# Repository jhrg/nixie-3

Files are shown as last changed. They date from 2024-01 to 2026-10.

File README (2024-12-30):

An alternative to the ShiftRegister74HC595 library is the builtin
shiftOut() function that is part of the Arduino IDE/libraries.

``` 
byte leds = 0;
bitSet(leds, i);

/*
 * updateShiftRegister() - This function sets the latchPin to low,
 * then calls the Arduino function 'shiftOut' to shift out contents
 * of variable 'leds' in the shift register before putting the 'latchPin' high again.
 */
void updateShiftRegister() {
    digitalWrite(latchPin, LOW);
    shiftOut(dataPin, clockPin, LSBFIRST, leds);
    digitalWrite(latchPin, HIGH);
}
```

Faster pin reads. See https://forum.arduino.cc/t/digital-read-write-pinmode-fast-execution/89116

// --- PIN MODE: OUTPUT  --- 

  DDRD |= _BV (0); // pinMode (0, OUTPUT);
  DDRD |= _BV (1); // pinMode (1, OUTPUT);
  DDRD |= _BV (2); // pinMode (2, OUTPUT);
  DDRD |= _BV (3); // pinMode (3, OUTPUT);
  DDRD |= _BV (4); // pinMode (4, OUTPUT);
  DDRD |= _BV (5); // pinMode (5, OUTPUT);
  DDRD |= _BV (6); // pinMode (6, OUTPUT);
  DDRD |= _BV (7); // pinMode (7, OUTPUT);
  DDRB |= _BV (0); // pinMode (8, OUTPUT);
  DDRB |= _BV (1); // pinMode (9, OUTPUT);
  DDRB |= _BV (2); // pinMode (10, OUTPUT);
  DDRB |= _BV (3); // pinMode (11, OUTPUT);
  DDRB |= _BV (4); // pinMode (12, OUTPUT);
  DDRB |= _BV (5); // pinMode (13, OUTPUT);
  DDRC |= _BV (0); // pinMode (A0, OUTPUT);
  DDRC |= _BV (1); // pinMode (A1, OUTPUT);
  DDRC |= _BV (2); // pinMode (A2, OUTPUT);
  DDRC |= _BV (3); // pinMode (A3, OUTPUT);
  DDRC |= _BV (4); // pinMode (A4, OUTPUT);
  DDRC |= _BV (5); // pinMode (A5, OUTPUT);

// --- PIN MODE: INPUT  --- 

  DDRD &= ~_BV (0); // pinMode (0, INPUT);
  DDRD &= ~_BV (1); // pinMode (1, INPUT);
  DDRD &= ~_BV (2); // pinMode (2, INPUT);
  DDRD &= ~_BV (3); // pinMode (3, INPUT);
  DDRD &= ~_BV (4); // pinMode (4, INPUT);
  DDRD &= ~_BV (5); // pinMode (5, INPUT);
  DDRD &= ~_BV (6); // pinMode (6, INPUT);
  DDRD &= ~_BV (7); // pinMode (7, INPUT);
  DDRB &= ~_BV (0); // pinMode (8, INPUT);
  DDRB &= ~_BV (1); // pinMode (9, INPUT);
  DDRB &= ~_BV (2); // pinMode (10, INPUT);
  DDRB &= ~_BV (3); // pinMode (11, INPUT);
  DDRB &= ~_BV (4); // pinMode (12, INPUT);
  DDRB &= ~_BV (5); // pinMode (13, INPUT);
  DDRC &= ~_BV (0); // pinMode (A0, INPUT);
  DDRC &= ~_BV (1); // pinMode (A1, INPUT);
  DDRC &= ~_BV (2); // pinMode (A2, INPUT);
  DDRC &= ~_BV (3); // pinMode (A3, INPUT);
  DDRC &= ~_BV (4); // pinMode (A4, INPUT);
  DDRC &= ~_BV (5); // pinMode (A5, INPUT);

// --- DIGITAL WRITE: HIGH  --- 

  PORTD |= _BV (0); // digitalWrite (0, HIGH);
  PORTD |= _BV (1); // digitalWrite (1, HIGH);
  PORTD |= _BV (2); // digitalWrite (2, HIGH);
  PORTD |= _BV (3); // digitalWrite (3, HIGH);
  PORTD |= _BV (4); // digitalWrite (4, HIGH);
  PORTD |= _BV (5); // digitalWrite (5, HIGH);
  PORTD |= _BV (6); // digitalWrite (6, HIGH);
  PORTD |= _BV (7); // digitalWrite (7, HIGH);

  PORTB |= _BV (0); // digitalWrite (8, HIGH);
  PORTB |= _BV (1); // digitalWrite (9, HIGH);
  PORTB |= _BV (2); // digitalWrite (10, HIGH);
  PORTB |= _BV (3); // digitalWrite (11, HIGH);
  PORTB |= _BV (4); // digitalWrite (12, HIGH);
  PORTB |= _BV (5); // digitalWrite (13, HIGH);

  PORTC |= _BV (0); // digitalWrite (A0, HIGH);
  PORTC |= _BV (1); // digitalWrite (A1, HIGH);
  PORTC |= _BV (2); // digitalWrite (A2, HIGH);
  PORTC |= _BV (3); // digitalWrite (A3, HIGH);
  PORTC |= _BV (4); // digitalWrite (A4, HIGH);
  PORTC |= _BV (5); // digitalWrite (A5, HIGH);

// --- DIGITAL WRITE: LOW  --- 

  PORTD &= ~_BV (0); // digitalWrite (0, LOW);
  PORTD &= ~_BV (1); // digitalWrite (1, LOW);
  PORTD &= ~_BV (2); // digitalWrite (2, LOW);
  PORTD &= ~_BV (3); // digitalWrite (3, LOW);
  PORTD &= ~_BV (4); // digitalWrite (4, LOW);
  PORTD &= ~_BV (5); // digitalWrite (5, LOW);
  PORTD &= ~_BV (6); // digitalWrite (6, LOW);
  PORTD &= ~_BV (7); // digitalWrite (7, LOW);

  PORTB &= ~_BV (0); // digitalWrite (8, LOW);
  PORTB &= ~_BV (1); // digitalWrite (9, LOW);
  PORTB &= ~_BV (2); // digitalWrite (10, LOW);
  PORTB &= ~_BV (3); // digitalWrite (11, LOW);
  PORTB &= ~_BV (4); // digitalWrite (12, LOW);
  PORTB &= ~_BV (5); // digitalWrite (13, LOW);
  
  PORTC &= ~_BV (0); // digitalWrite (A0, LOW);
  PORTC &= ~_BV (1); // digitalWrite (A1, LOW);
  PORTC &= ~_BV (2); // digitalWrite (A2, LOW);
  PORTC &= ~_BV (3); // digitalWrite (A3, LOW);
  PORTC &= ~_BV (4); // digitalWrite (A4, LOW);
  PORTC &= ~_BV (5); // digitalWrite (A5, LOW);

// --- DIGITAL READ  --- 

  x = (PIND & _BV (0)) == 0; // digitalRead (0);
  x = (PIND & _BV (1)) == 0; // digitalRead (1);
  x = (PIND & _BV (2)) == 0; // digitalRead (2);
  x = (PIND & _BV (3)) == 0; // digitalRead (3);
  x = (PIND & _BV (4)) == 0; // digitalRead (4);
  x = (PIND & _BV (5)) == 0; // digitalRead (5);
  x = (PIND & _BV (6)) == 0; // digitalRead (6);
  x = (PIND & _BV (7)) == 0; // digitalRead (7);
  x = (PINB & _BV (0)) == 0; // digitalRead (8);
  x = (PINB & _BV (1)) == 0; // digitalRead (9);
  x = (PINB & _BV (2)) == 0; // digitalRead (10);
  x = (PINB & _BV (3)) == 0; // digitalRead (11);
  x = (PINB & _BV (4)) == 0; // digitalRead (12);
  x = (PINB & _BV (5)) == 0; // digitalRead (13);
  x = (PINC & _BV (0)) == 0; // digitalRead (A0);
  x = (PINC & _BV (1)) == 0; // digitalRead (A1);
  x = (PINC & _BV (2)) == 0; // digitalRead (A2);
  x = (PINC & _BV (3)) == 0; // digitalRead (A3);
  x = (PINC & _BV (4)) == 0; // digitalRead (A4);
  x = (PINC & _BV (5)) == 0; // digitalRead (A5);

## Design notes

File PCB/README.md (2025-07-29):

## Ideal Project Structure

    my_kicad_project/
    ├── my_project.kicad_sch
    ├── my_project.kicad_pcb
    ├── my_project.kicad_pro
    ├── footprints/
    │   └── custom_footprint.pretty/
    └── symbols/
        └── custom_symbol.kicad_sym

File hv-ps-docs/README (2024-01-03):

Scope images showing the affect of adding a resistor from the anode to
ground (marked 'w-gnd') so that anode current can drain off when using
PWM to control brightness of a nixe tube. Measured using the 'nixe-3'
board where each tube has its own BCD to dec driver 74151 which
are each connected to a 74HC595 serial to 8-bit parallel chip.

This shows that adding the resistor does not make much difference in the
turn off time and no difference in the turn on time. The images were taken
at the brightest and dimest PWN settings.

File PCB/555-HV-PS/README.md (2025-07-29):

# 555 HV Power supply for Nixie tubes

This is a power supply for nixie tubes based on the 555 timer chip. The 555 is configured in its astable mode with a frequency of ~32kHz.

When I used this, it has some ripple in the output and there is some slight ghosting of the digits that I think is from noise affecting the serial output to the nixie 3.2 driver board. When I use a commercial supply that has cleaner output, there is no ghosting. However, it might be that noise from my breadboard version of the HV PS is the problem and not the output itself.

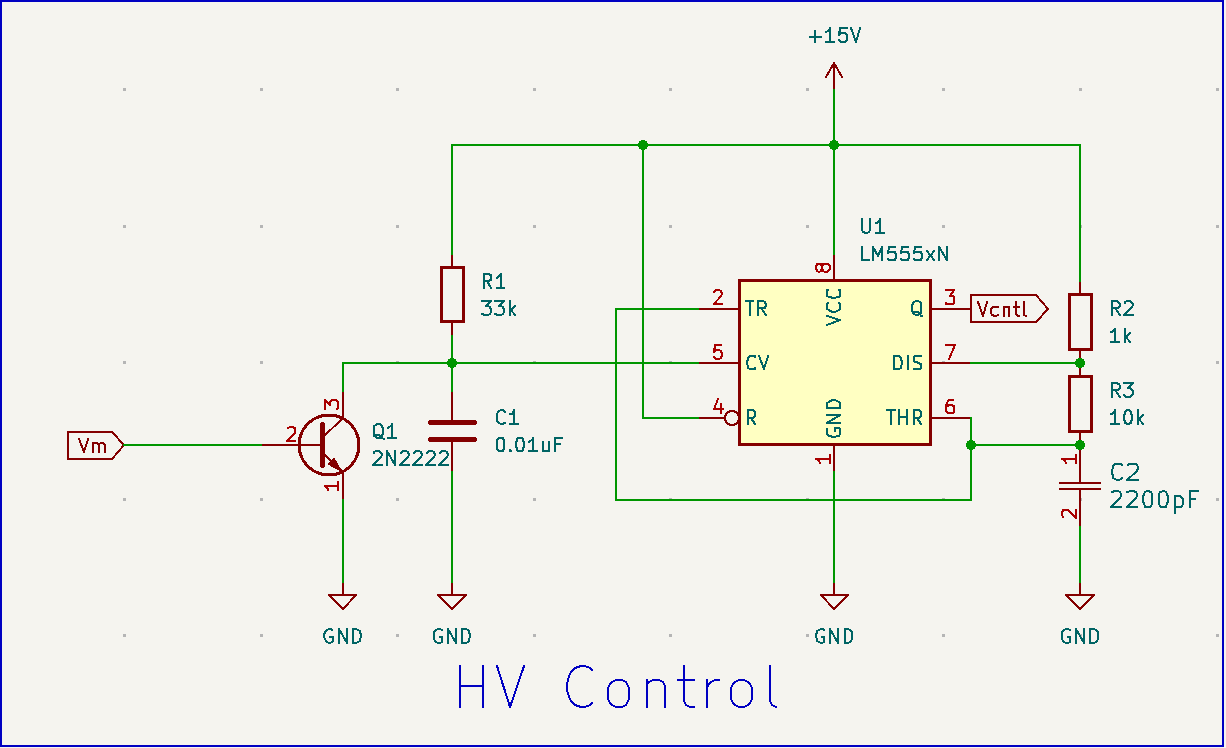
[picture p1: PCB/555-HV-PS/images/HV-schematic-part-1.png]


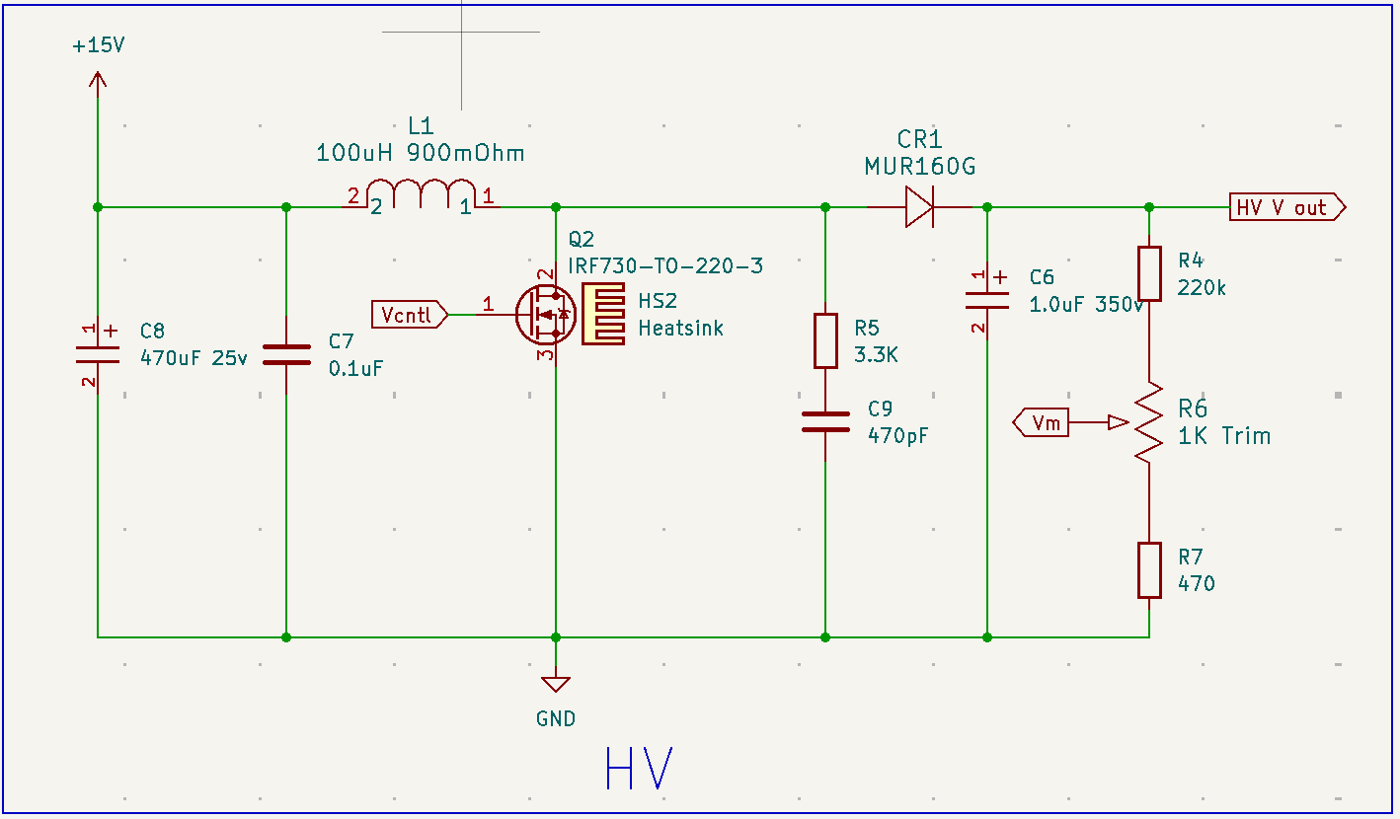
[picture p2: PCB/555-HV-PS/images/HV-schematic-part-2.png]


## About the RC snubber

R5 and C9 are a RC snubber to limit ringing at the from Q2 when it switches off. 
In these images, yellow is the hig voltage at the inductor-diode-Q2 junction or the
HV output of the PS and magenta is the switching voltage from pin 3 of the 555 (i.e.,
the gate of Q2).

Without the RC snubber, there is ringing when Q2 turns off:

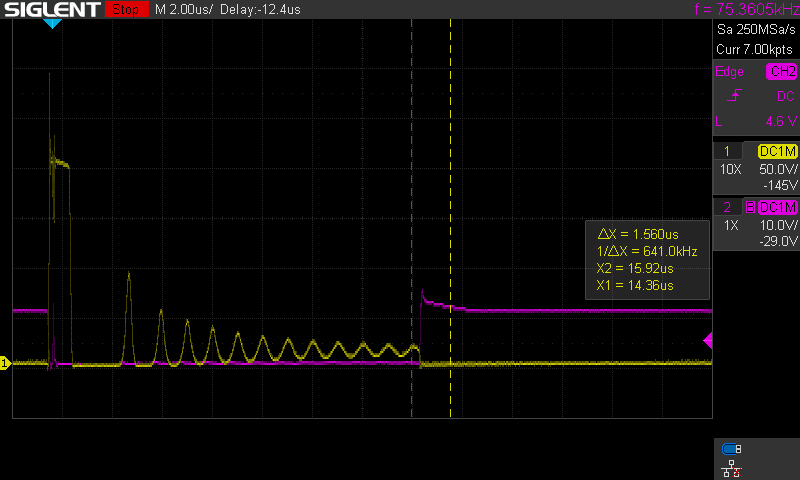
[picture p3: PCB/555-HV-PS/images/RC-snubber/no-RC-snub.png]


The snubber circuit can damp this ringing - that might help clean up the output.
Here are the effects of various values of R5 and C9. I choose R5 at 15k and C9
as 100pF initially based on info from [DigiKey's article on RC snubbers for power switches](https://www.digikey.com/en/articles/resistor-capacitor-rc-snubber-design-for-power-switches).

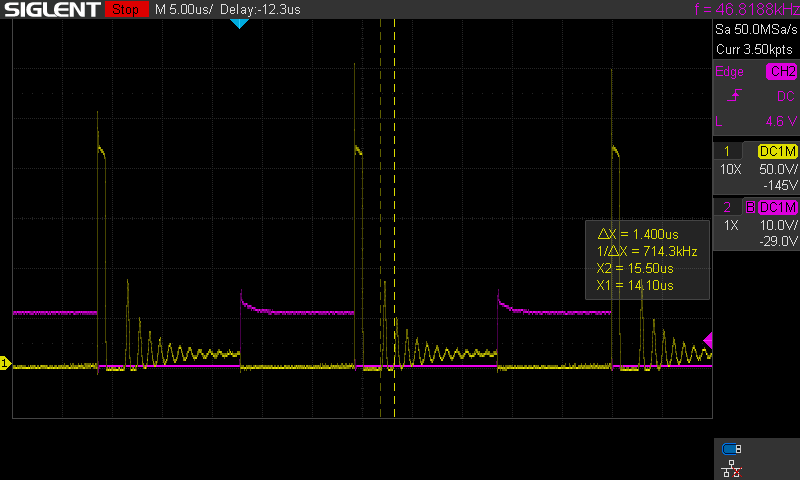
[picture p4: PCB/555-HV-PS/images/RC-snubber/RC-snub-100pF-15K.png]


Some improvement.

Dropping R5 down to 1K makes a bigger difference, but the efficiency of the PS
drops (the current draw goes from 370mA to 400mA):

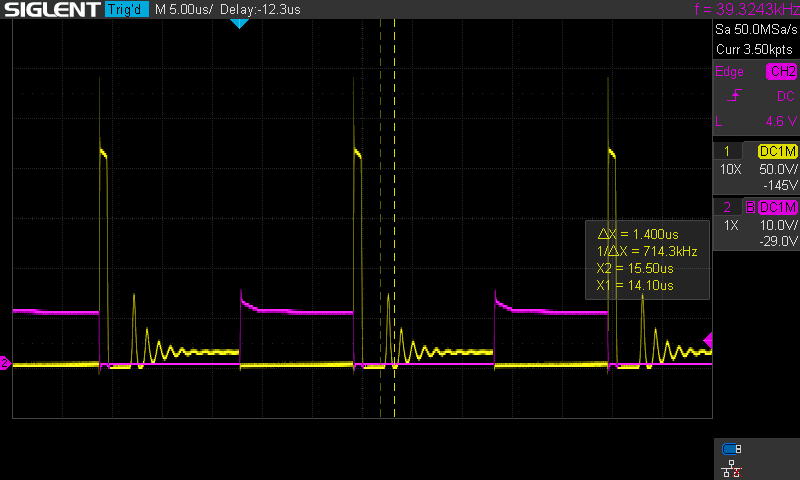
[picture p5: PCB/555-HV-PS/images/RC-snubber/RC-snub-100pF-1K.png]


Increasing C9 to 470pF makes an even bigger improvement, but the PS is still drawing 400mA
@12V from the bench supply:

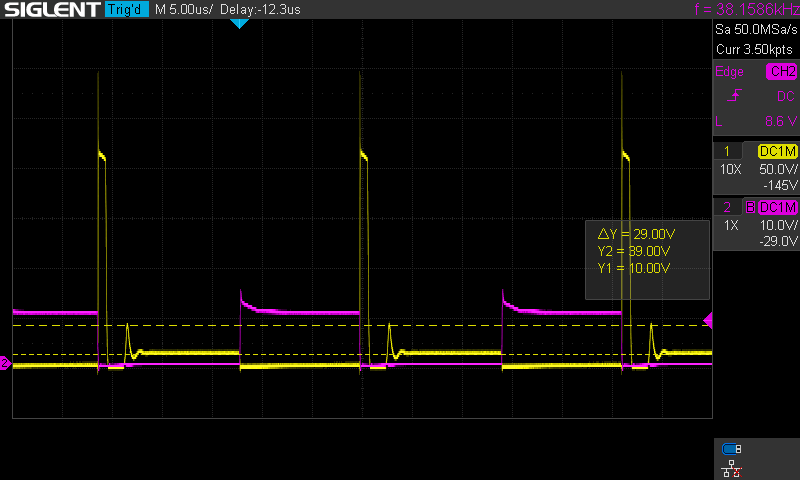
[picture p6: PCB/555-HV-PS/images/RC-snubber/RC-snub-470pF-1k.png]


Increasing R5 to 3.3K reduces the power needed (back to 370mA @12V) with decent damping:

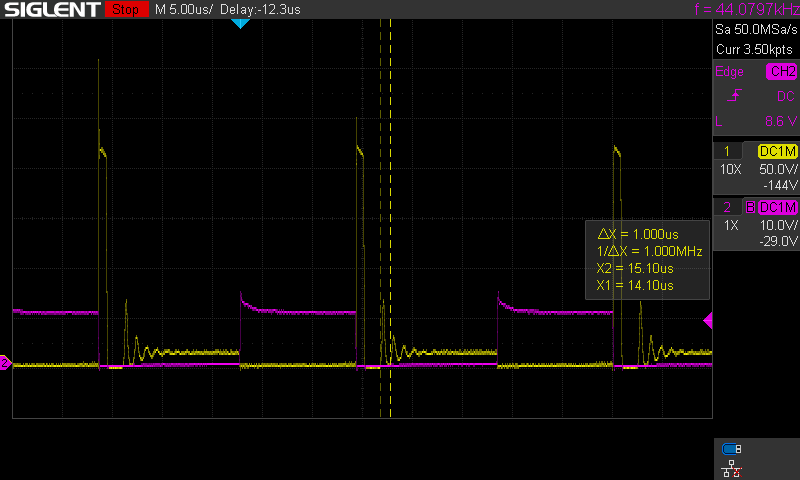
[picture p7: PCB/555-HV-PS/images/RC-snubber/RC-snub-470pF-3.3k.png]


The output of the PS looks like:

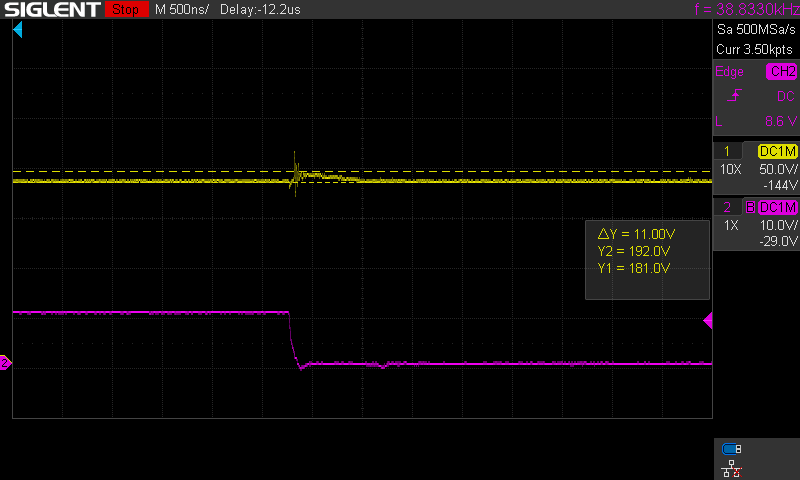
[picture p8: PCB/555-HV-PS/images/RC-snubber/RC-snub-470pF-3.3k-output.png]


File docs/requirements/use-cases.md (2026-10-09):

<!-- CONTRACT: actor-driven flows through the system. Each use case is what ties
     functional requirements together into something a real user actually does.
     Delete the _EXAMPLE_ use case once you've seen the shape. -->

# Use Cases

Convention: `UC-###`. Each use case follows the template below. Link related `FR-###`
/ `NFR-###` IDs at the bottom so `/trace` can find them in both directions.

---

## UC-001 — Adjust display brightness

**Actor(s):** Day-to-day user of the clock

**Trigger:** Quick (momentary) press of button 1

**Preconditions:** Clock is powered on and running (any display mode)

**Main flow:**
1. User gives a quick press on button 1
2. System advances to the next brightness level in the preset sequence
   (`brightness_count`), wrapping back to the brightest level after the dimmest
3. System applies the new PWM level to the HV brightness control pin immediately

**Alternate / exception flows:**
- None currently handled — every quick press of button 1 advances brightness
  regardless of current display mode

**Postconditions:** Display brightness is at the newly selected preset level until
the next quick press

**Related requirements:** FR-003

---

## UC-002 — Switch between MM:SS and HH:MM display mode

**Actor(s):** Day-to-day user of the clock

**Trigger:** Quick (momentary) press of button 2

**Preconditions:** Clock is powered on and running

**Main flow:**
1. User gives a quick press on button 2
2. System toggles the display mode between `mm_ss` and `hh_mm`
3. System renders the four Nixie tubes using the digits for the newly selected mode
   on the next time-update tick

**Alternate / exception flows:**
- None currently handled — medium (~2s) and long (~5s) presses of either button are
  currently no-ops, reserved for a future task/feature

**Postconditions:** Clock continues displaying time in the newly selected mode until
the next quick press of button 2

**Related requirements:** FR-001

---

<!-- Copy the template above for each new use case. Sequential UC-### heading,
     same subsection order, so /trace can parse it. -->

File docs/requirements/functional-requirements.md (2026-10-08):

<!-- CONTRACT: what the system must DO. One row per requirement. IDs are permanent —
     never renumbered or reused. Dropped requirements get Status: Deprecated /
     Superseded, not deleted. Delete the _EXAMPLE_ row once you've seen the shape. -->

# Functional Requirements

Convention: `FR-###`, zero-padded, assigned sequentially by next-highest-number.
Priority: `Must` / `Should` / `Could` (MoSCoW). Status: `Proposed` / `Approved` /
`Implemented` / `Deprecated` / `Superseded by FR-0XX`.

| ID | Requirement | Priority | Related Use Cases | Status |
|---|---|---|---|---|
| FR-001 | Display the current time on four Nixie tubes, switchable between MM:SS and HH:MM modes via a button press | Must | UC-002 | Implemented |
| FR-002 | Maintain accurate time using an external RTC (DS3231 or DS1307) that survives power cycles | Must | — | Implemented |
| FR-003 | Allow brightness adjustment via a push-button that cycles through preset PWM brightness levels | Must | UC-001 | Implemented |
| FR-004 | Flash the colon/separator once per second as a visible seconds indicator | Must | — | Implemented |

<!-- Add new rows via /new-requirement, or by hand — keep the table format. Each
     requirement should be a single testable statement, not a paragraph. If it needs
     a paragraph, it's probably a use case (docs/requirements/use-cases.md) with this
     as one of its acceptance criteria. -->

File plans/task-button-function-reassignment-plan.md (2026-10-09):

# Task Plan: Reassign button functions: button 1 = brightness, button 2 = display mode

**Task:** TASK-002
**Status:** Done
**Created:** 2026-10-08

## Summary

Swap which button drives which action: button 1's quick press keeps controlling
brightness, button 2's quick press takes over display-mode toggling (currently that's
a ~2s hold on button 1). Both buttons' medium (~2s) and long (~5s) presses become
explicit no-ops, reserved for future use. UC-001 and UC-002 are updated to match.

## Motivation

Today both buttons' quick presses do the identical thing (advance brightness), and
mode-switching is hidden behind a 2-second hold on button 1 that a user has to
discover or be told about. Splitting the two actions across the two buttons' quick
presses gives each button a distinct, easily-discoverable role, and frees up the
medium/long press duration on *both* buttons for a future task or feature (per user
request — out of scope here).

## Related requirements / constraints

- FR-001 — "switchable between MM:SS and HH:MM modes via a button press." Wording
  doesn't name a specific button, so no FR text change is needed; the use case that
  specializes it (UC-002) does need updating.
- FR-003 — "brightness adjustment via a push-button that cycles through preset PWM
  brightness levels." Same situation: button-agnostic wording, no FR change needed.
- UC-001 (Adjust display brightness) — currently documents the trigger as "quick
  press of button 1 or button 2." Updated by this task to "button 1" only.
- UC-002 (Switch between MM:SS and HH:MM) — currently documents the trigger as "medium
  press (~2s) of button 1." Updated by this task to "quick press of button 2."
- No IC/ADR found that bears on this change.

## Scope

**In scope:**
- `src/main.cpp`, `loop()`:
  - Button 1 (`read_button_1()`) switch: `quick` keeps calling
    `input_switch_quick_press()` (unchanged behavior). `medium_2s` and `long_5s`
    become explicit no-op cases (currently `medium_2s` calls
    `input_switch_medium_press()`; `long_5s` already falls through `default`).
  - Button 2 (`read_button_2()`) switch: `quick` calls the display-mode toggle
    (currently `input_switch_medium_press()`, invoked from button 1's `medium_2s`
    case) instead of `input_switch_quick_press()`. `medium_2s` and `long_5s` become
    explicit no-op cases (`medium_2s` is already a no-op today but implicit; make it
    explicit alongside `long_5s` for symmetry).
  - Rename `input_switch_medium_press()` to a name that doesn't reference "medium"
    duration, since it's no longer tied to a medium-length press (e.g.
    `toggle_display_mode()`). Logic inside the function is unchanged.
  - Remove the stale `// Replace this with ...` comment above button 2's switch,
    since this task is exactly that replacement.
  - Add a short comment on each new no-op case noting it's reserved for a future
    task/feature, so the empty branch doesn't read as an oversight.
- `docs/requirements/use-cases.md`:
  - UC-001: change Trigger to "Quick (momentary) press of button 1." Update the main
    flow's "either push button" wording to "button 1." Update/remove the alternate
    flow note that currently says "every quick press advances brightness regardless
    of current display mode" if it no longer applies, or reword to reflect
    single-button triggering.
  - UC-002: change Trigger to "Quick (momentary) press of button 2." Update the main
    flow's "holds button 1 for a medium press duration" wording to "gives a quick
    press on button 2." Replace the alternate-flow note about button 2's medium press
    having no assigned behavior — that's now moot — with a note that both buttons'
    medium (~2s) and long (~5s) presses are currently no-ops, reserved for future use.
- `docs/tasks/TASK-LOG.md`: already updated to `Plan Ready` with this plan linked.

**Out of scope:**
- `include/button_timing.h` / `src/button_timing.cc` — press-duration classification,
  thresholds (`SWITCH_PRESS_2S`/`SWITCH_PRESS_5S`), and debounce timing are untouched.
  TASK-001 (native test env + extraction of this module) is independent of this
  rewiring and currently `In Progress`; this task doesn't depend on it finishing.
- `read_button_1()` / `read_button_2()`, the ISR handlers, or `mode_switch_setup()` in
  `src/mode_switch2.cc` — press detection and debouncing logic is unchanged.
- Any assigned behavior for the medium (~2s) or long (~5s) presses on either button —
  explicitly deferred to a future task/feature per the user's request.
- FR-001 / FR-003 wording — already button-agnostic, no change needed.
- Adding a native unit test for the button-dispatch `switch` statements in
  `loop()` — this logic is tightly coupled to Arduino globals (`analogWrite`,
  `the_display_mode`, `brightness`) and isn't extracted into a testable module;
  extracting it would be new scope (and overlaps what TASK-001 is already doing for
  the press-duration side), not part of this reassignment.
- Any change to pin assignments, ISR attachment, or interrupt trigger types in
  `include/pins.h` or `mode_switch_setup()`.

## Approach

1. In `src/main.cpp`, rename `input_switch_medium_press()` to `toggle_display_mode()`
   (keep its signature/body as-is — it already takes and returns `enum
   display_mode`).
2. Rewrite button 1's `switch (read_button_1())`:
   - `case quick:` — unchanged, calls `input_switch_quick_press()`.
   - `case medium_2s:` — becomes `break;` with a one-line comment ("no-op; reserved
     for future task/feature").
   - `case long_5s:` — add explicit case with the same no-op + comment (previously
     implicit via `default`).
   - `default:` — unchanged (`break;`).
3. Rewrite button 2's `switch (read_button_2())`:
   - `case quick:` — now calls `the_display_mode =
     toggle_display_mode(the_display_mode);` instead of
     `input_switch_quick_press()`.
   - `case medium_2s:` — explicit no-op + comment (was already an empty case;
     keep it, just add the comment for symmetry with button 1).
   - `case long_5s:` — add explicit case, no-op + comment.
   - `default:` — unchanged.
   - Remove the `// Replace this with ...` comment above this switch.
4. Update `docs/requirements/use-cases.md` UC-001 and UC-002 per the Scope section
   above (Trigger, main flow wording, alternate-flow notes).
5. Build for the target env (`pio run`) to confirm it still compiles — no native
   test exists for this dispatch logic (see Out of scope), so this is a compile +
   manual/on-device check, not a unit-test pass.

Completeness check: since this only touches two `switch` statements in one function
plus one renamed function and two UC sections, completeness is verified by reading
the full diff of `src/main.cpp` and `docs/requirements/use-cases.md` against this
plan's enumerated changes above — no grep-count needed given the small, fixed set of
edit sites.

## Verification

- `pio run` builds clean for the target board environment (no new warnings beyond
  whatever baseline currently exists).
- `pio check` run against the touched file, per CLAUDE.md's static-analysis
  convention.
- Manual on-device check (per CLAUDE.md: anything that must touch real silicon is
  verified on-target, not unit tested): quick-press button 1 → brightness advances;
  quick-press button 2 → display mode toggles between MM:SS and HH:MM; hold either
  button ~2s or ~5s → nothing happens.
- Diff review of `src/main.cpp` and `docs/requirements/use-cases.md` against the
  Scope section to confirm nothing beyond the listed edit sites changed.

## Risks

- `toggle_display_mode()`'s rename could miss a call site if one exists outside
  `main.cpp` — mitigated by grepping for `input_switch_medium_press` before and after
  to confirm zero remaining references.
- Since button 2's quick press previously shared `input_switch_quick_press()` with
  button 1, removing that call means button 2 no longer touches `brightness`/
  `HV_PWM_CONTROL` at all — worth confirming no other code path assumed button 2
  could also drive brightness.

## Open questions

None — scope, category, and the UC-doc update were confirmed with the user before
drafting this plan.

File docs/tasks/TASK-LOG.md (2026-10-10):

<!-- CONTRACT: scoped engineering/maintenance work that isn't new capability (FR/NFR/
     UC) and isn't corrective (BUG) — dependency bumps, removing dead code or stale
     compile-time directives, retrofitting tests onto code that predates them,
     build/tooling changes. The common thread: the "right" outcome is usually
     mechanical and completeness matters (did every instance get handled?), not
     open-ended design. Delete the TASK-EXAMPLE section once you've seen the shape. -->

# Task Log

Convention: `TASK-###`, sequential, never renumbered. Status: `Open` → `Plan Ready` →
`In Progress` → `Done` (or `Won't Do` / `Superseded by TASK-0XX`). **Only the user sets
`Done`** — it's a claim about verified work, not something to self-report from having
written a plan. Category is one of: Dependency
Update, Code Cleanup, Test Coverage, Build/Tooling, Documentation (add categories as
needed).

---

## TASK-001 — Add native PlatformIO test environment, extracting button press-duration classification as a first unit-testable module

**Category:** Build/Tooling
**Status:** In Progress
**Created:** 2026-10-07
**Related requirements/constraints:** None found — stems from CLAUDE.md's testing
convention, not a tracked FR/NFR/IC. Underpins button behavior in FR-001, FR-003,
UC-001, UC-002 without changing it.
**Plan:** `plans/task-native-test-env-plan.md`

**Scope:** Add `[env:native]` to `platformio.ini`, standalone (not inheriting
`[env]`'s Arduino-only `lib_deps`/`build_flags`). Extract the press-duration
classification currently duplicated in `read_button_1()`/`read_button_2()`
(`src/mode_switch2.cc`) into `include/button_timing.h` + `src/button_timing.cc`,
with no `Arduino.h` dependency, and add a Unity test under
`test/test_button_timing/`. Does not extract any other logic (brightness
wraparound, digit-from-time computation, debounce timing itself), change button
behavior/thresholds, assign `read_button_2()`'s unused `medium_2s` case, or
introduce a `lib/` subfolder layout — each is out of scope for this task.

**Motivation:** No way currently exists to run any unit test without a board
attached; CLAUDE.md's testing convention calls for `env:native` but it was never
added. Flagged as a known gap during the `/init-planning` session rather than
invented independently.

---

## TASK-002 — Reassign button functions: button 1 = brightness, button 2 = display mode

**Category:** Code Cleanup
**Status:** In Progress
**Created:** 2026-10-08
**Related requirements/constraints:** FR-001 (mode switching via button press — wording
is button-agnostic, no change needed), FR-003 (brightness cycling via push-button —
wording is button-agnostic, no change needed). UC-001 and UC-002 explicitly document
the *current* button-to-function mapping and will be updated as part of this task to
match the new mapping.
**Plan:** `plans/task-button-function-reassignment-plan.md`

**Scope:** Rewire the button dispatch in `src/main.cpp`'s `loop()` so button 1's quick
press still drives brightness (unchanged) and button 2's quick press drives the
display-mode toggle (moved off button 1's medium ~2s press). Button 1's and button
2's medium (~2s) and long (~5s) presses become explicit no-ops. Update UC-001 and
UC-002 in `docs/requirements/use-cases.md` to describe the new mapping. Does not
touch `button_timing.cc/h`, press-duration thresholds, debounce timing, the ISR
handlers, `read_button_1()`/`read_button_2()`, or assign any behavior to the 2s/5s
presses themselves (reserved for a future task/feature) — each is out of scope.

**Motivation:** Today both buttons' quick presses do the same thing (brightness), and
mode-switching is buried behind a 2-second hold on button 1 — a less discoverable,
less evenly-distributed mapping. Reassigning gives each button a distinct quick-press
role and frees up both buttons' medium/long presses for future use, per user request.

---

## TASK-003 — Separate hardware-touching code from logic-only code for three more functions, extending TASK-001's pattern

**Category:** Code Cleanup
**Status:** Plan Ready
**Created:** 2026-10-09
**Related requirements/constraints:** None found — stems from CLAUDE.md's hardware-
adapter-layer convention, not a tracked FR/NFR/IC. The logic being extracted
underpins FR-001 (display mode), FR-003 (brightness), and FR-002/UC-002 (time
display) without changing any of their behavior.
**Plan:** `plans/task-hardware-logic-separation-plan.md`

**Scope:** Extract three more pieces of logic that TASK-001 explicitly deferred,
decoupling each from `Arduino.h` and (for the time-digit case) from RTClib's
`DateTime` type, and add a native Unity test for each: (1) the brightness-index
wraparound in `main.cpp`'s `input_switch_quick_press()`, (2) `main.cpp`'s already-pure
`toggle_display_mode()`, relocated into its own translation unit, and (3) the
digit-from-time/date decomposition in `RTC.cc`'s `update_display_with_time()` /
`update_display_with_date()`, rewritten to take plain integers instead of `DateTime`.
Does not touch debounce timing, the ISR handlers, `read_button_1()`/`read_button_2()`,
or remove `update_display_with_date()` despite it currently being unused — each is
out of scope.

**Motivation:** Sets the stage for more complete unit-test coverage by continuing the
hardware/logic separation TASK-001 started and explicitly deferred for these three
pieces, per user request.

---

<!-- Add new tasks via /plan-task, or by hand — keep the section format: metadata
     lines, then Scope / Motivation. Unlike a bug, a task doesn't need a symptom or
     reproduction — it needs a clear boundary of what's included and what isn't,
     since "remove all the X" quietly becoming "remove most of the X" is the
     characteristic failure mode here. -->

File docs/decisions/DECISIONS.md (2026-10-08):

<!-- CONTRACT: WHY things are the way they are. Never a log of what happened (that's
     git history / plans/) — only calls that could plausibly have gone another way,
     with the reasoning captured so it isn't re-litigated from scratch in six months. -->

# Decisions

Convention: `ADR-###`, sequential, never renumbered. A superseded decision stays in
the file with `Status: Superseded by ADR-0XX` — the reasoning that led somewhere wrong
is often as useful later as the reasoning that led somewhere right.

---

## ADR-EXAMPLE — Use a time-limited link, not a one-time code, for password reset

*(delete this section once you've seen the shape)*

**Date:** YYYY-MM-DD
**Status:** Accepted

**Context:** Password reset needed a mechanism that works from any device, including
one the user isn't currently signed in on.

**Decision:** Emailed link with a signed, expiring token, rather than a numeric code
entered back into the original device.

**Alternatives considered:**
- Numeric code — simpler to implement, but assumes the user is on the same device
  they requested from, which broke for a chunk of support tickets historically.

**Consequences:** Reset flow now depends on transactional email deliverability, which
becomes a new failure mode to monitor (see IC-EXAMPLE if a related constraint exists).

**Related:** FR-EXAMPLE, UC-EXAMPLE

---

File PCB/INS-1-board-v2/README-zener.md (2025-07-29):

## Zener diode power sources for INS-1 Nixie Tubes
### July 1, 2025
Asking ChatGPT about a Power supply for INS-1 Nixie tubes using a zener diode.
Here’s how you size the series resistor (and check its power) step-by-step:

1. List your parameters

Supply voltage: 
$VV_\text{in}=180\text{ V}$

Zener voltage: 
$VV_Z=91\text{V}$ (measured at its test current $I_{Zt}=4\text{ mA}$)

Tube load current: two tubes × 0.5 mA each ⇒ $I_L=1\text{ mA}$

Desired Zener bias: use the data sheet test current, 
$I_{Z,\text{bias}}=I_{Zt}=4\text{ mA}$

2. Compute resistor value
You need to supply both load and Zener bias current through RR.
$RR = \frac{V_\text{in}-V_Z}{I_L + I_{Z,\text{bias}}} =\frac{180-91}{1\,\text{ mA}+4\,\text{ mA}} =\frac{89\text{ V}}{5\text{ mA}} =17.8\text{ kΩ}$
Use the nearest standard: 18 kΩ.

3. Check currents (at any Vin variation)
At nominal 180 V:
$I_R = \frac{180-91}{18\,\text{kΩ}}\approx4.94\text{ mA} \quad\Longrightarrow\quad I_Z = I_R - I_L \approx 4.94 - 1 = 3.94\text{ mA}$
That’s essentially the 4 mA bias—right at the knee.

If the supply dipped to, say, 175 V:
 $I_R = \frac{175-91}{18\,\text{kΩ}}\approx4.67\text{ mA} \quad\Longrightarrow\quad I_Z\approx3.67\text{ mA}$
 Still above the knee current, so regulation holds.

If it rose to 185 V:
 $I_R = \frac{185-91}{18\,\text{kΩ}}\approx5.22\text{ mA} \quad\Longrightarrow\quad I_Z\approx4.22\text{ mA}$
 Well below any damaging level.

4. Check power dissipation
   1. Resistor:
 $PR=(Vin−VZ)×IR≈89 V×0.005 A=0.445 W P_R = (V_\text{in}-V_Z)\times I_R \approx 89\text{ V}\times0.005\text{ A} =0.445\text{ W}$
 ⇒ use at least a 1 W resistor (or a ½ W with good ventilation, but 1 W is safer).
   1. Zener:
 $PZ=VZ×IZ,bias=91 V×0.004 A=0.364 W P_Z = V_Z \times I_{Z,\text{bias}} =91\text{ V}\times0.004\text{ A} =0.364\text{ W}$
 ⇒ choose a Zener rated ≥ ½ W (or 1 W for head-room).

5. Final parts choice
Series resistor: 18 kΩ, 1 W

Zener diode: 91 V, ≥ 0.5 W (1 W preferred)

Optional: a small (0.1 µF–1 µF) bypass cap across the Zener if you ever see switching noise—though if your supply is very clean, it’s not strictly needed.

With that in place, your two Nixies (1 mA total) will see a rock-steady 91 V clamp, fed from your 180 V rail via the 18 kΩ/1 W resistor.

About using the common emitter-follower + zener configuration

Adding an emitter–follower (i.e. a high-voltage NPN or N-channel device acting as a buffer) behind your Zener lets the Zener only source the transistor’s base (or gate) current instead of the entire tube load.  In practice that means:

1. **Much lower Zener bias current**

   * In our straight Zener clamp, the series resistor had to supply $I_L + I_{Z}$, e.g. 1 mA for the tubes plus 4 mA for the Zener → 5 mA total.
   * With an emitter-follower, the Zener only needs to supply the transistor’s base current:

     $I_B \approx \frac{I_E}{\beta}$

     If your transistor has a DC current gain ($\beta$) of, say, 100, then for 1 mA emitter current you only need \~10 µA of base current.  You’d typically pick a few tens of µA of Zener bias (say 50 µA) to keep it in regulation—two orders of magnitude less than before.

2. **Series-resistor power drops drastically**

   * Old design:

     $P_R = (180 - 91)\,\text{V} \times 5\,\text{mA} \approx 0.445\,\text{W}$

     ⇒ needed a ≥1 W resistor.
   * Emitter-follower design: if you set $I_{Z}+I_B\approx50\,\mu\text{A}$,

     $P_R = 89\,\text{V} \times 50\,\mu\text{A} \approx 4.5\,\text{mW}$

     ⇒ a tiny 1/10 W (or even 1/20 W) part is plenty.

3. **Zener diode dissipation plunges**

   * Previously $P_Z = 91\,\text{V}\times4\,\text{mA}\approx0.36\,\text{W}$.
   * Now $P_Z = 91\,\text{V}\times50\,\mu\text{A}\approx4.5\,\text{mW}$.

4. **Where the power goes**

   * The transistor now drops roughly the same 89 V at 1 mA, so
     $P_{\!Q}\approx89\,\text{mW}$.  That’s still small—any small HV-rated transistor (or MOSFET source follower) can handle it without a heat-sink.

5. **Voltage-drop considerations**

   * The emitter sits one
     $V_{BE}$ (\~0.6–0.8 V) below the Zener.  So if you clamp the base at 91 V, your tubes see \~90.2 V.  Make sure that still exceeds their strike voltage (91 V) or bump the Zener up a notch (e.g. 92 V).

---

### Bottom line

* **Yes**, with an emitter-follower you can reduce the Zener’s resistor and the Zener itself to wattages down in the milliwatt range.
* The trade-off is added complexity and the need for a high-voltage transistor (or MOSFET) rated above your 180 V rail.
* Regulation will also be **stiffer** (lower noise and better load-regulation) than a bare Zener clamp.

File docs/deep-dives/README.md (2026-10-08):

<!-- CONTRACT: persisted findings from code investigations, so a deep dive doesn't
     have to be redone from scratch next time someone asks the same question. This
     is DESCRIPTIVE (what the code currently does) — it is not DECISIONS.md (why a
     choice was made) and not a requirement doc (what the system should do). If code
     and docs/requirements disagree, a deep-dive note is where that gets flagged for
     someone to resolve, not where it gets silently reconciled either direction. -->

# Deep Dives

One file per investigation, named `<slug>.md`, written by `/deep-dive`. Each starts
with the date and the question that prompted it, so a stale note (code has since
changed) is recognizable as possibly outdated rather than trusted as current fact.

Nothing else goes in this folder by hand-convention beyond that — the shape of each
note follows the question it's answering, not a fixed template.

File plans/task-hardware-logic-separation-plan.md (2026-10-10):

# Task Plan: Separate hardware-touching code from logic-only code for three more functions

**Task:** TASK-003
**Status:** Done
**Created:** 2026-10-09

## Summary

Extract three pieces of logic that TASK-001 identified but explicitly deferred —
brightness-index wraparound, display-mode toggle, and digit-from-time/date
decomposition — out from behind `Arduino.h` (and, for the digit decomposition, out
from behind RTClib's `DateTime` type) into plain C++ functions, each with a native
Unity test, following the pattern TASK-001 established for button press-duration
classification.

## Motivation

CLAUDE.md's hardware-adapter-layer convention calls for algorithmic logic to live in
plain C++ that doesn't include `Arduino.h`, confined to a thin adapter layer
otherwise. TASK-001 built the `env:native` test environment and proved the pattern
with one extraction (`classify_press_duration()`), but its Scope section explicitly
deferred "brightness-index wraparound ... digit-from-time computation ... debounce
timing itself" as separate future candidates. This task picks up the first two of
those three and adds a related third (the display-mode toggle), per user request, to
set the stage for more complete unit-test coverage.

## Related requirements / constraints

None found in `docs/requirements/` or `docs/constraints/` — this task stems from
CLAUDE.md's testing/hardware-adapter convention, not a tracked FR/NFR/IC. The logic
being extracted underpins:
- FR-003 (brightness adjustment via push-button) — brightness-index wraparound.
- FR-001 (display mode switchable between MM:SS/HH:MM) — display-mode toggle.
- FR-002 (accurate time via RTC) and UC-002 — digit-from-time/date decomposition.

This task changes none of that behavior; it only relocates and tests existing logic.

## Scope

**In scope:**

1. **Brightness-index wraparound** (`src/main.cpp:89-93`,
   `input_switch_quick_press()`):
   - New `include/brightness.h` / `src/brightness.cc`, no `Arduino.h` include.
   - `uint8_t next_brightness_index(uint8_t current_index, uint8_t level_count)` —
     returns `0` if `current_index == level_count - 1`, else `current_index + 1`.
     Matches the existing inline ternary exactly; `level_count` is computed at the
     call site the same way it is today
     (`sizeof(brightness_count)/sizeof(brightness_count[0])`).
   - `input_switch_quick_press()` becomes: compute the new index via
     `next_brightness_index()`, assign it to `brightness`, then keep the existing
     `DPRINTV("brightness: %d\n", brightness)` and `analogWrite(...)` calls at the
     call site (logging and hardware I/O are not part of the pure function).

2. **Display-mode toggle** (`src/main.cpp:95-109`, `toggle_display_mode()`):
   - Declare `enum display_mode toggle_display_mode(enum display_mode display_mode)`
     in `include/mode_switch2.h` (which already defines `enum display_mode` and has
     no `Arduino.h` dependency — no new header needed).
   - Move the implementation to a new `src/display_mode.cc`, with the function body
     unchanged except dropping the `DPRINTV(...)` call (which depends on
     `print.h`'s `F()`/`Arduino.h`-coupled macro). The equivalent log line moves to
     the call site in `main.cpp`'s `loop()`, immediately after the call to
     `toggle_display_mode()`.

3. **Digit-from-time/date decomposition** (`src/RTC.cc:37-58`,
   `update_display_with_time()` / `update_display_with_date()`):
   - New `include/display_digits.h` / `src/display_digits.cc`, no `Arduino.h` or
     RTClib include.
   - A plain struct `display_digits { int d0, d1, d2, d3, d4, d5; };` and two pure
     functions:
     - `display_digits digits_from_time(int hour, int minute, int second)`
     - `display_digits digits_from_date(int year, int month, int day)`
     reproducing the existing `%10` / `/10` arithmetic exactly (including the
     existing `(year - 2000) / 10` behavior for the two-digit year).
   - `update_display_with_time()` / `update_display_with_date()` in `RTC.cc` become
     thin wrappers: call the new function with `dt.hour()`, `dt.minute()`, etc.,
     and assign the result's fields to the six `volatile int digit_N` globals.
     `DateTime` itself stays confined to `RTC.cc`.

4. **`platformio.ini` / test infrastructure:**
   - Add `brightness.cc`, `display_mode.cc`, and `display_digits.cc` to
     `[env:native]`'s `build_src_filter` (alongside the existing
     `+<button_timing.cc>`).
   - Add `test/test_brightness/test_brightness.cpp`,
     `test/test_display_mode/test_display_mode.cpp`, and
     `test/test_display_digits/test_display_digits.cpp` (Unity, following
     `test/test_button_timing/test_button_timing.cpp`'s structure).

**Out of scope:**
- Debounce timing and the ISR handlers in `mode_switch2.cc`
  (`button_1_interrupt_handler()`, `button_2_interrupt_handler()`,
  `read_button_1()`, `read_button_2()`) — TASK-001 already deferred debounce timing
  itself, and this task doesn't revisit that call.
- `toggle_separator()` in `RTC.cc` — its only non-hardware content is a single
  boolean flip, not substantial enough to extract on its own.
- Removing `update_display_with_date()` despite it currently having no call site
  (confirmed via `grep -rn "update_display_with_date" src include` — only the
  definition at `RTC.cc:49` and no callers). It's wired up the same as
  `update_display_with_time()` by this task, but whether the function itself is
  dead code is a separate question from hardware/logic separation — flagged here
  as a candidate for a future Code Cleanup task, not addressed in this one.
- Changing `brightness`'s or `digit_0`..`digit_5`'s types away from `volatile int`
  — out of scope; this task only changes how their new values are computed.
- Enabling `-Werror` or resolving any existing `pio check` findings outside the
  files this task touches.
- Introducing a `lib/` subfolder layout (same exclusion TASK-001 made).

## Approach

1. Add `include/brightness.h` / `src/brightness.cc` with `next_brightness_index()`.
   Update `main.cpp`'s `input_switch_quick_press()` to call it.
2. Add `toggle_display_mode()`'s declaration to `include/mode_switch2.h`; move its
   implementation to `src/display_mode.cc`, dropping the internal `DPRINTV` call;
   add the equivalent log line at the call site in `main.cpp`'s `loop()`. Remove the
   old definition from `main.cpp`.
3. Add `include/display_digits.h` / `src/display_digits.cc` with `display_digits`,
   `digits_from_time()`, `digits_from_date()`. Rewrite `RTC.cc`'s
   `update_display_with_time()` / `update_display_with_date()` to call them.
4. Update `[env:native]`'s `build_src_filter` in `platformio.ini` to include the
   three new `.cc` files.
5. Add the three new Unity test files under `test/`, each covering: a mid-range
   value, the wraparound/rollover boundary (e.g. `next_brightness_index()` at
   `level_count - 1`), and the two-digit split behavior (e.g. `digits_from_time()`
   at `hour=0`, `hour=23`, `minute=0`, `second=59`; `digits_from_date()` at a
   two-digit-year boundary like `year=2000` and `year=2099`).
6. Enumerate the three extractions as a checklist and confirm each is complete:
   - [ ] `next_brightness_index()` extracted, `main.cpp` has no inline wraparound
     arithmetic left (`grep -n "brightness ==" src/main.cpp` returns nothing).
   - [ ] `toggle_display_mode()` moved out of `main.cpp`
     (`grep -n "^enum display_mode toggle_display_mode" src/main.cpp` returns
     nothing; the declaration lives only in `mode_switch2.h`).
   - [ ] `digits_from_time()` / `digits_from_date()` extracted, `RTC.cc`'s two
     `update_display_with_*` functions contain no `%10`/`/10` arithmetic directly
     (`grep -n "% 10\|/ 10" src/RTC.cc` returns nothing outside the new file).
7. Run `pio test -e native` and confirm all four test suites
   (`button_timing` + the three new ones) pass.
8. Run `pio run -e uno` and `pio run -e pro16MHzatmega328` and confirm both still
   build clean.
9. Run `pio check` and `clang-format` over every touched/added file.

## Verification

- `pio test -e native` passes, covering all cases listed in Approach step 5.
- `pio run -e uno` and `pio run -e pro16MHzatmega328` both build with no new
  warnings beyond whatever the codebase already emits.
- All three checklist greps in Approach step 6 come back empty, confirming the
  logic was relocated rather than duplicated.
- Manual read-through of each new pure function against the code it replaced
  confirms identical arithmetic and boundary behavior — a behavior change here
  would silently alter FR-001/FR-003 behavior or UC-002's displayed time.
- `pio check` runs clean (or any new finding justified inline per CLAUDE.md).

## Risks

- Dropping the `DPRINTV` call from inside `toggle_display_mode()` and
  `input_switch_quick_press()`'s pure half, and re-adding equivalent logging at the
  call site, is a small structural change to *where* a debug line is emitted
  (same information, same logical point in `loop()`) — low risk, but worth a
  deliberate diff check rather than assuming it's a no-op.
- `digits_from_time()`/`digits_from_date()` replacing direct `DateTime` field
  access with explicit `int` parameters relies on `DateTime::hour()`/`minute()`/
  etc. all returning types that convert losslessly to `int` — true today, but worth
  confirming during implementation rather than assumed.
- Low overall risk otherwise: all three extractions are small, pure, and intended
  to be behavior-preserving; the main failure mode is a subtle arithmetic slip
  between old and new code, which the checklist greps and manual read-through are
  meant to catch.

## Open questions

- None blocking.

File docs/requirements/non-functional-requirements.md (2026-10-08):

<!-- CONTRACT: quality attributes the system must meet, with a measurable target where
     possible. "Fast" and "user-friendly" are not requirements — a number or a
     testable condition is. Delete the _EXAMPLE_ row once you've seen the shape. -->

# Non-Functional Requirements

Convention: `NFR-###`. Category is one of: Performance, Security, Reliability,
Availability, Scalability, Usability, Maintainability, Compliance, Observability
(add categories as needed — keep the list here in sync). Priority: `Must` / `Should`
/ `Could`. Status as in functional-requirements.md.

| ID | Category | Requirement | Measurable Target | Priority | Status |
|---|---|---|---|---|---|

_(none yet — no hard NFR targets have been confirmed as of the initial planning
interview; add rows via `/new-requirement` as targets are decided — e.g. time drift/
accuracy, HV supply limits, brightness PWM frequency, power-on recovery time.)_

<!-- If you genuinely can't state a measurable target yet, write TBD in that column
     rather than a vague phrase — TBD is honest and searchable; "reasonably fast"
     just looks finished. -->

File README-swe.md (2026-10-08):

# claude-swe-planning-template

A Claude Code project template for **requirements-driven planning**: write your
functional requirements, non-functional requirements, use cases, and implementation
constraints as plain markdown with stable IDs, and have Claude produce implementation
plans that cite those IDs — instead of planning from a conversation's worth of
half-remembered context.

This is a sibling idea to session-continuity templates like
[claude-config-public](https://github.com/OPENDAP/claude-config-public), which solves
a different problem (picking a research project back up after a month away). This
template solves: *"before Claude plans a feature, has it actually read what we agreed
the system should do, and will the plan say which requirement each step satisfies?"*

## What you get

```
CLAUDE.md                                   # rules Claude reads every session
docs/
  requirements/
    functional-requirements.md              # FR-001, FR-002, ...
    non-functional-requirements.md          # NFR-001, ...
    use-cases.md                             # UC-001, ...
  constraints/
    implementation-constraints.md            # IC-001, ... — hard boundaries
  decisions/
    DECISIONS.md                             # ADR-001, ... — why, not what
  bugs/
    BUG-LOG.md                               # BUG-001, ... — report → root cause → fix
  tasks/
    TASK-LOG.md                              # TASK-001, ... — scoped maintenance/engineering work
  deep-dives/
    README.md                                # convention note; one file per investigation
plans/
  _template-plan.md                          # shape every generated feature plan follows
  _template-bugfix.md                        # shape every generated bugfix plan follows
  _template-task.md                          # shape every generated task plan follows
.claude/
  commands/
    init-planning.md      # /init-planning   — first-time interview & doc seeding
    plan-feature.md        # /plan-feature    — requirements → phased plan
    fix-bug.md              # /fix-bug         — log a bug, find root cause, plan the fix
    deep-dive.md             # /deep-dive       — read-only code investigation, saved findings
    new-requirement.md     # /new-requirement — add an FR/NFR/UC/IC by interview
    plan-task.md             # /plan-task       — log a maintenance/engineering task, draft a plan
    trace.md                # /trace           — find every reference to an ID
    audit-plan.md           # /audit-plan      — check a plan's citations, report only
  agents/
    requirements-reviewer.md  # subagent that reviews docs for vague/untestable language
  settings.json            # example permission scaffold — verify against current docs
```

Every requirement, use case, and constraint gets a stable ID (`FR-001`, `NFR-014`,
`UC-003`, `IC-002`). Plans in `plans/` cite those IDs on every phase. `/trace` and
`/audit-plan` exist so that "does anything actually cover this?" and "did this plan
wander off scope?" are one command away instead of a manual grep.

**Bugs get a parallel ID space, `BUG-###`, deliberately not folded into the FR/NFR/UC
shape.** A bug isn't new capability satisfying a requirement — it's existing behavior
deviating from one (or from something that was never written down in the first
place). `/fix-bug` logs it, investigates root cause read-only, and drafts a bugfix
plan with regression risk and verification steps instead of delivery phases.

**Tasks get a third parallel ID space, `TASK-###`.** Not new capability like an FR,
not a correction like a bug — scoped engineering work such as dependency bumps,
removing dead compile-time directives, or retrofitting tests onto code that predates
them. `/plan-task` logs it and drafts a plan that emphasizes scope (exactly what's
in, what's explicitly out) and how completeness gets checked, since this kind of
task tends to fail quietly — a few instances missed — rather than loudly like a
broken build.

**`/deep-dive` is a standalone, read-only investigation command** for understanding
existing code — onboarding to an unfamiliar module, answering "how does X work,"
or checking whether the code still matches what the requirement docs claim. Findings
get saved to `docs/deep-dives/` so the same investigation doesn't happen twice.
`/plan-feature` and `/fix-bug` both hand off to it when what they need is more than a
quick read-only look.

## Using this as a template

**Option A — GitHub template repository.** Push this to GitHub, then in
**Settings → General**, check **"Template repository."** After that, **Use this
template** on the repo page (or `gh repo create my-project --template
<you>/claude-swe-planning-template`) gives you a fresh copy with its own history for
every new project.

**Option B — copy into an existing repo.** Copy `CLAUDE.md`, `docs/`, `plans/`, and
`.claude/` into a repo you already have (if it already has a `CLAUDE.md` or
`.claude/settings.json`, merge rather than overwrite). Nothing in the core template
assumes a particular language or stack — the `.claude/` folder and `docs/` folder are
additive. Language-specific snippets (currently `arduino-platformio-conventions.md` and
`cpp-conventions.md`) are optional: paste the one you want into the Conventions section of `CLAUDE.md`. Run `/init-planning`
afterward to seed the requirement docs from the existing codebase and an interview,
rather than starting from blank tables.

## First steps in a new project

1. Fill in `{{PROJECT_NAME}}`, `{{ONE_LINE_DESCRIPTION}}`, and `{{CONVENTIONS}}` in
   `CLAUDE.md` — or run `/init-planning` and let the interview do it.
2. Delete the `_EXAMPLE_` rows in each `docs/requirements/*.md` and
   `docs/constraints/*.md` file once you've seen the format — they're there to show
   the table shape, not to be real requirements.
3. Run `/new-requirement` a few times to populate real FRs/NFRs/UCs/ICs, or `/init-
   planning` to do it as one interview.
4. Run `/plan-feature <something>` and check that the plan it writes to `plans/`
   actually cites the IDs you just wrote.

## Design choices worth knowing about

- **IDs are never renumbered or reused.** A dropped requirement is marked
  `Superseded` or `Deprecated`, not deleted — otherwise a plan written last month
  cites an ID that silently means something else now.
- **Claude is instructed not to invent requirements.** If you ask for a feature with
  no backing FR/UC, `/plan-feature` will say so and offer `/new-requirement` rather
  than writing a plausible-sounding one and treating it as fact.
- **`/trace` and `/audit-plan` only report — they never edit.** Traceability checks
  that silently "fix" things by rewriting docs are how requirements quietly drift
  from what was actually agreed.
- **`.claude/settings.json` is an illustrative starting point**, not a verified
  current schema — Claude Code's settings format can change; check
  https://docs.claude.com/en/docs/claude-code/overview before relying on it.

## License

MIT — use it, change it, ship it.

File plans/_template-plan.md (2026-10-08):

<!-- Shape for every plan written to plans/. /plan-feature follows this structure.
     This file itself is never a real plan — copy the shape, don't edit this one. -->

# Plan: {{FEATURE NAME}}

**Status:** Draft | In Review | Approved | In Progress | Done
**Created:** {{DATE}}

## Summary

One or two sentences: what this delivers and why now.

## Requirements traced

Every FR / NFR / UC this plan satisfies, listed explicitly — not just mentioned inline
in the phases below, so `/audit-plan` and a human skimming can see coverage at a
glance.

- FR-###, FR-### — ...
- NFR-### — ...
- UC-### — ...

## Constraints considered

Every IC that bears on this plan, and how the plan respects it (or, if it can't,
an explicit flag rather than a silent workaround).

- IC-### — ...

## Phases

### Phase 1 — {{name}}

**Goal:** ...
**Satisfies:** FR-###, UC-###

Steps:
1. ...
2. ...

**Risks:** ...

### Phase 2 — {{name}}

(repeat as needed — keep phases small enough to review and land independently)

## Open questions

Genuine unknowns — not filled with a plausible guess. Each should block a specific
phase until answered, or say why it doesn't.

- ...

## Out of scope

What this plan deliberately does not cover, so it isn't quietly assumed later.

- ...

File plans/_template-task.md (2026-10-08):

<!-- Shape for task plans written to plans/task-<slug>-plan.md by /plan-task.
     This file itself is never a real plan — copy the shape, don't edit this one.
     Deliberately not the same shape as _template-plan.md: a task isn't new capability
     tied to FR/NFR/UC. Deliberately not the same shape as _template-bugfix.md:
     nothing is necessarily broken. What a task shares with a bugfix plan is that
     scope and completeness matter more than phased delivery. -->

# Task Plan: {{TASK TITLE}}

**Task:** TASK-###
**Status:** Draft | In Review | Approved | In Progress | Done
**Created:** {{DATE}}

## Summary

One or two sentences: what this changes and why.

## Motivation

Why this, why now. A task doesn't need an FR/NFR/UC behind it the way a feature
does — but if there's a related requirement, constraint, or a pattern of bugs that
motivated it, say so.

## Related requirements / constraints

Optional — leave `None` if this task exists independent of the requirement docs
(e.g. retrofitting tests onto code that predates them).

- FR-### / NFR-### / IC-### — how it relates

## Scope

**In scope:** exactly what's included — specific enough that "is this file part of
the task" has an obvious answer.

**Out of scope:** what looks related but isn't included, so it doesn't get folded in
mid-task or assumed covered when it isn't.

## Approach

Steps:
1. ...
2. ...

For anything mechanical (removing every instance of X, updating every dependency in
a set), include how completeness is being checked — a `grep` count before and after,
a list enumerated up front and checked off — not just "done when it looks done."

## Verification

How to confirm the task is actually complete and nothing else broke — full test
suite, build across the platforms this project targets, a diff review of every
touched file. For test-coverage tasks, what coverage looks like before and after.

## Risks

What could go wrong or regress as a side effect of a change that touches many
files or dependencies at once.

## Open questions

Genuine unknowns — not filled with a plausible guess. Each should block the task
until answered, or say why it doesn't.

- ...

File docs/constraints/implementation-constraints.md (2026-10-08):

<!-- CONTRACT: things that constrain HOW the system can be built, independent of
     what it must do. These are boundaries, not preferences — if a plan would cross
     one, that's a flag, not a quiet redesign. Delete the _EXAMPLE_ row once you've
     seen the shape. -->

# Implementation Constraints

Convention: `IC-###`. Category is one of: Technology/Platform, Infrastructure/
Deployment, Regulatory/Compliance, Organizational/Team, Third-Party/Integration,
Budget/Timeline (add categories as needed).

| ID | Category | Constraint | Rationale | Impact on design |
|---|---|---|---|---|

_(none yet beyond the Arduino/C++ conventions already in `CLAUDE.md` — confirmed during
the initial planning interview. Add rows via `/new-requirement` if a hard boundary
beyond those conventions is identified.)_

<!-- A constraint is not the same as a non-functional requirement: an NFR describes
     a quality the system should have (and can trade off); a constraint is a boundary
     condition that plans must work within, full stop. If it's negotiable, it's
     probably an NFR with a priority, not a constraint. -->

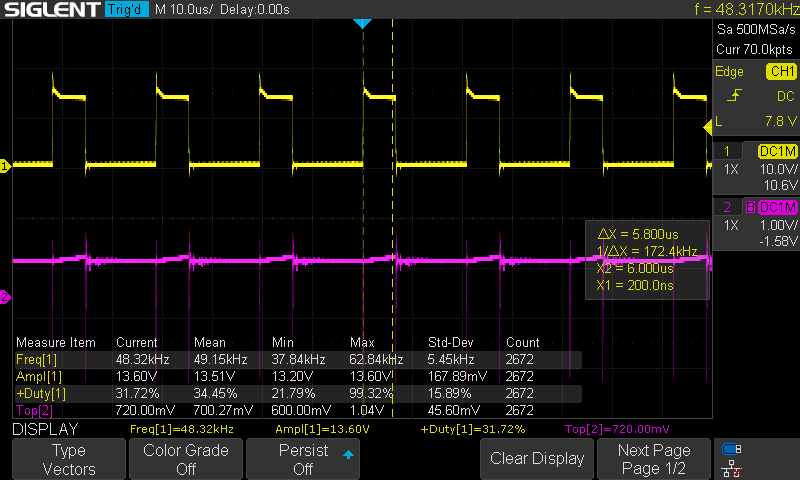
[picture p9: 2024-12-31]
PCB/555-HV-PS/images/160v.png

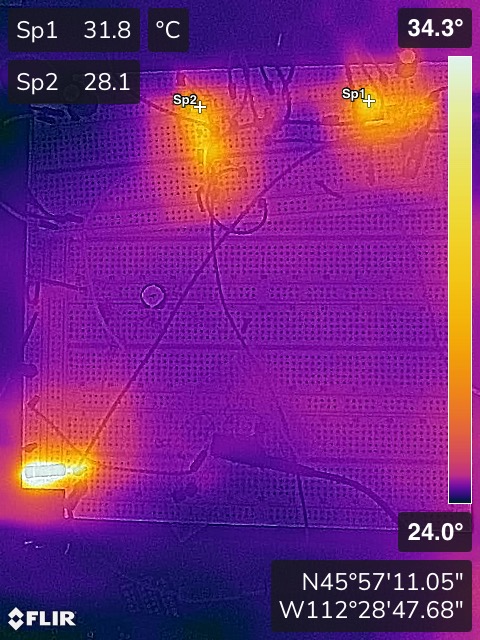
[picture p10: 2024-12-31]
PCB/555-HV-PS/images/Thermal image ~6mA load.jpg

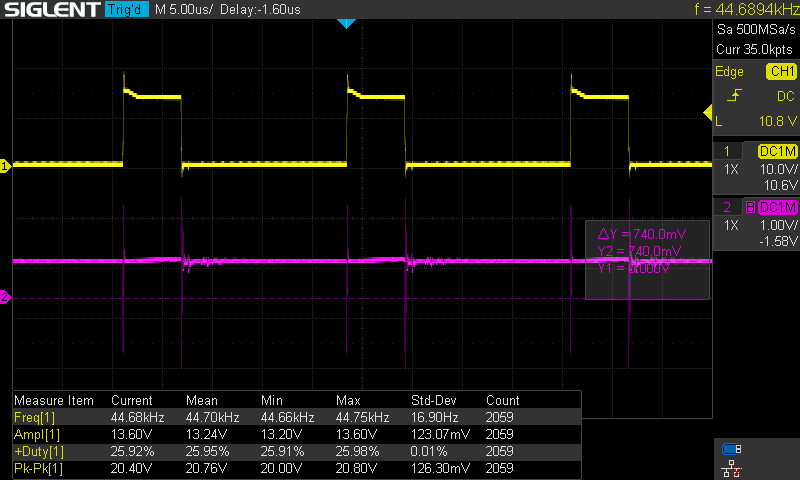
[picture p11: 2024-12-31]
PCB/555-HV-PS/images/555-HV-PS-10.22.24.png

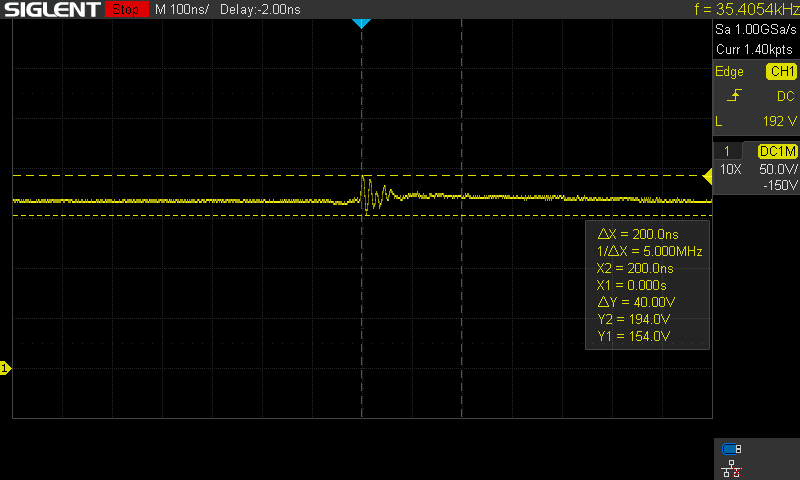
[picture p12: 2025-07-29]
PCB/555-HV-PS/images/555-HV-PS-without-snubber.png

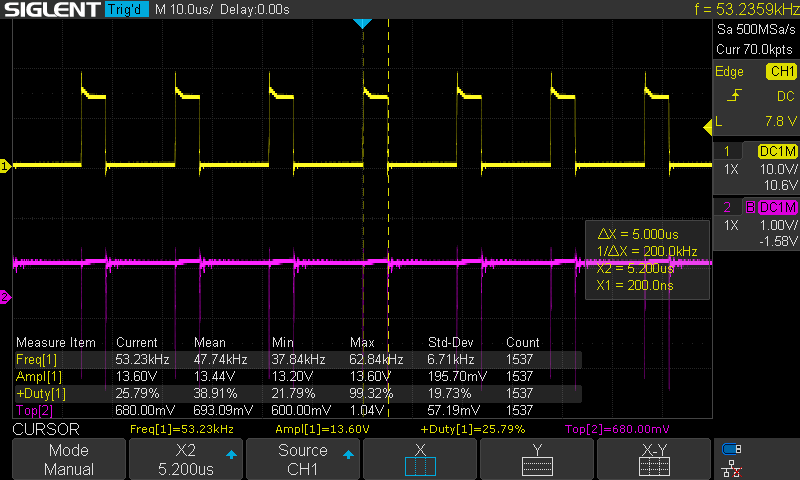
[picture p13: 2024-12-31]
PCB/555-HV-PS/images/130v.png

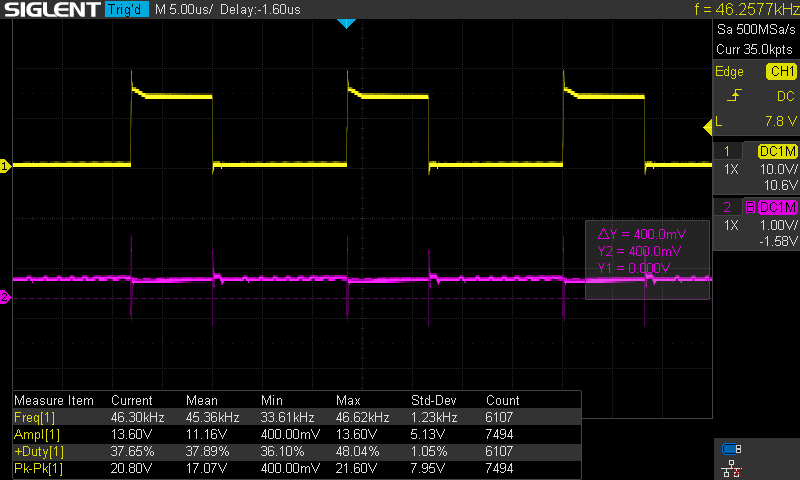
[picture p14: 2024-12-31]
PCB/555-HV-PS/images/555-Driving-HV-PS.png

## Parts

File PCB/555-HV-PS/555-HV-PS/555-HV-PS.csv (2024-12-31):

Reference | Value | Datasheet | Footprint | Qty | DNP
C1 | 1.0uF 100V | ~ | S222M-2n2F-cer-disk:1.0uF_160V_CAPPRD200W50D525H1250 | 1
C2 | 0.1uF 50V | ~ | Capacitor_THT:C_Disc_D5.0mm_W2.5mm_P5.00mm | 1
C3 | 470uF 25v |  | S222M-2n2F-cer-disk:WCAP-ATUL_10X16_DXL_470uF-25v | 1
C4 | 100pF | ~ | Capacitor_THT:C_Disc_D4.3mm_W1.9mm_P5.00mm | 1
C5 | 0.1uF | ~ | Capacitor_THT:C_Disc_D5.0mm_W2.5mm_P5.00mm | 1
C6 | 0.01uF | ~ | Capacitor_THT:C_Disc_D4.3mm_W1.9mm_P5.00mm | 1
C7 | 1.0uF 350v |  | S222M-2n2F-cer-disk:WCAP-ATET_8X11.5_DXL_ | 1
C8 | 2200pF | S222M29Z5UN6UJ5R | CAP_S-SERIES_N-29-J_VIS | 1
CR1 | MUR160G |  | S222M-2n2F-cer-disk:MUR160G | 1
D1 | 1N5819 | http://www.vishay.com/docs/88525/1n5817.pdf | Diode_THT:D_DO-41_SOD81_P10.16mm_Horizontal | 1
F1 | 30V 500mA | ~ | HVPS-555:AHRF050_30v_500mA_polyfuse | 1
H1,H2,H3,H4 | MountingHole | ~ | MountingHole:MountingHole_3mm | 4
HS1 | Heatsink | ~ | S222M-2n2F-cer-disk:AVVID-577202B-00000G | 1
J1 | Barrel_Jack_Switch | ~ | S222M-2n2F-cer-disk:BarrelJack_Horizontal | 1
J2 | Conn_3_screw | OSTVN03A150 | CONN3_OSTVN03A150_OST | 1
L1 | 100uH 900mA | 744772101 | IND_8095-WE-TI_8p3x10x5_WRE | 1
Q1 | 2N2222 | https://www.onsemi.com/pub/Collateral/2N3903-D.PDF | Package_TO_SOT_THT:TO-92_Inline | 1
Q2 | IRF730-TO-220-3 | https://media.digikey.com/pdf/Data%20Sheets/Fairchild%20PDFs/BUZ11.pdf | Package_TO_SOT_THT:TO-220-3_Vertical | 1
R1 | 56k | ~ | Resistor_THT:R_Axial_DIN0207_L6.3mm_D2.5mm_P10.16mm_Horizontal | 1
R2 | 1M | ~ | Resistor_THT:R_Axial_DIN0207_L6.3mm_D2.5mm_P10.16mm_Horizontal | 1
R3 | 220k | ~ | Resistor_THT:R_Axial_DIN0207_L6.3mm_D2.5mm_P10.16mm_Horizontal | 1
R4 | 1K Trim |  | S222M-2n2F-cer-disk:10k_Trimmer_PV36W103C01B00 | 1
R5 | 470 | ~ | Resistor_THT:R_Axial_DIN0207_L6.3mm_D2.5mm_P10.16mm_Horizontal | 1
R6 | 1k | ~ | Resistor_THT:R_Axial_DIN0207_L6.3mm_D2.5mm_P10.16mm_Horizontal | 1
R7 | 10k | ~ | Resistor_THT:R_Axial_DIN0207_L6.3mm_D2.5mm_P10.16mm_Horizontal | 1
U1 | LM7805_TO220 | https://www.onsemi.cn/PowerSolutions/document/MC7800-D.PDF | Package_TO_SOT_THT:TO-220-3_Vertical | 1
U2 | LM555xN | http://www.ti.com/lit/ds/symlink/lm555.pdf | Package_DIP:DIP-8_W7.62mm | 1

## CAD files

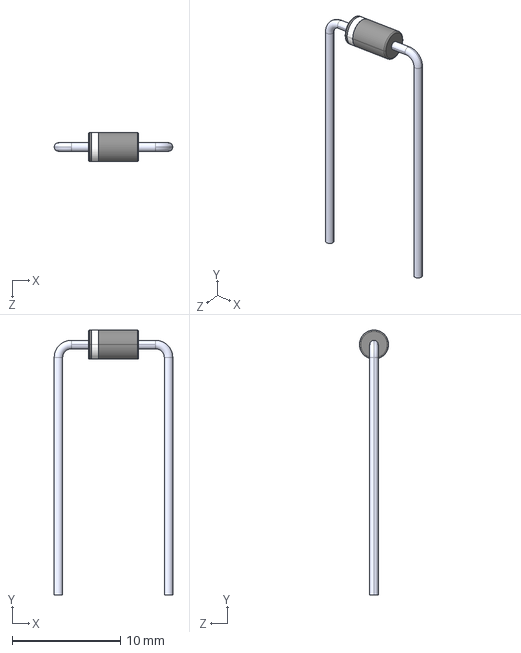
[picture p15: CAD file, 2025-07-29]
PCB/INS-1-board-v2/1N5948BRLG/1N5948BRLG.step
10.9 x 24.5 x 2.69 mm

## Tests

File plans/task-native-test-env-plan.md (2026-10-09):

# Task Plan: Add native PlatformIO test environment, extracting button press-duration classification as a first unit-testable module

**Task:** TASK-001
**Status:** Done
**Created:** 2026-10-07

## Summary

Add an `[env:native]` PlatformIO environment so hardware-independent logic can be
unit-tested on the host, and prove it out by extracting the button
press-duration classification (elapsed ms → `quick` / `medium_2s` / `long_5s`) out
from behind `Arduino.h` into a plain C++ function with a real Unity test.

## Motivation

CLAUDE.md's testing convention requires an `env:native` target so logic-layer code
gets host-run unit tests, but `platformio.ini` currently only defines `uno`,
`pro16MHzatmega328`, and `hv_ps_test` — there is no way to run any test without a
board attached. Flagged as a gap during the `/init-planning` session
(2026-10-07) rather than invented independently.

Scaffolding alone (an empty `env:native` with no real test) would prove the
toolchain works but not that it's useful, so this task also extracts one
self-contained piece of logic to validate the pattern end-to-end.

## Related requirements / constraints

None found in `docs/requirements/` or `docs/constraints/` — this task stems from
the testing convention in `CLAUDE.md`, not a tracked FR/NFR/IC. The logic being
extracted underpins button-driven behavior described in FR-001, FR-003, UC-001,
and UC-002, but this task changes nothing about that behavior — it only relocates
and tests existing logic.

## Scope

**In scope:**
- Add `[env:native]` to `platformio.ini` (`platform = native`, no `board =`),
  defined standalone rather than inheriting `${env.build_flags}` /
  `${env.lib_deps_builtin}` / `${env.lib_deps_external}` from `[env]`, since those
  pull in Arduino-only libraries (`SPI`, `Wire`, `PinChangeInterrupt`,
  `adafruit/RTCLib`) that don't exist for the native platform.
- Extract the press-duration classification logic currently duplicated in
  `read_button_1()` and `read_button_2()` (`src/mode_switch2.cc:128-134` and
  `:169-175`) into a new pure function:
  - `include/button_timing.h` — declares
    `enum switch_press_duration classify_press_duration(long elapsed_ms)`, plus the
    `SWITCH_PRESS_2S` / `SWITCH_PRESS_5S` threshold constants (currently `#define`d
    privately in `mode_switch2.cc`).
  - `src/button_timing.cc` — implementation. No `Arduino.h` include, no
    hardware calls — pure arithmetic over its input.
- Update `mode_switch2.cc` to call `classify_press_duration(elapsed)` in both
  `read_button_1()` and `read_button_2()` instead of the duplicated inline
  if/else chain. Thresholds and return values must be unchanged.
- Configure `env:native`'s `build_src_filter` (or equivalent) so the native test
  build compiles only `button_timing.cc` — excluding `main.cpp`,
  `mode_switch2.cc`, `RTC.cc`, and `print.cc`, all of which include `Arduino.h`
  and would fail to compile natively.
- Add `test/test_button_timing/test_button_timing.cpp` (PlatformIO/Unity
  convention) covering: a value just under 2000ms → `quick`; exactly at and just
  over the 2000ms boundary → `medium_2s`; just under and at/over the 5000ms
  boundary → `long_5s`; a 0ms / negative value if the function's contract allows
  it (decide during implementation whether negative elapsed is a defined input or
  a precondition violation, and document whichever is chosen).

**Out of scope:**
- Extracting any other logic (brightness-index wraparound in `main.cpp`,
  digit-from-time computation in `RTC.cc`, debounce timing itself) — each is a
  separate candidate for a future task, not folded into this one.
- Changing button behavior, thresholds, or adding the currently-unassigned
  `read_button_2()` `medium_2s` behavior (`main.cpp`'s `// Replace this with ...`
  comment) — unrelated to test infrastructure.
- Introducing a `lib/` subfolder structure for this or future modules — this task
  keeps the project's existing flat `include/` + `src/` convention rather than
  introducing a new layout choice as a side effect.
- Enabling `-Werror` or resolving any existing `pio check` findings outside the
  files this task touches.

## Approach

1. Add `include/button_timing.h` and `src/button_timing.cc` with
   `classify_press_duration()`, moving the `SWITCH_PRESS_2S` / `SWITCH_PRESS_5S`
   constants there from `mode_switch2.cc`.
2. Update both call sites in `src/mode_switch2.cc` to use the new function;
   remove the now-duplicated inline logic. `grep -n "SWITCH_PRESS_"
   src/mode_switch2.cc` should return zero matches afterward (the constants now
   live only in `button_timing.h`).
3. Add `[env:native]` to `platformio.ini` per the Scope section above.
4. Add the Unity test file under `test/test_button_timing/`.
5. Run `pio test -e native` and confirm it passes.
6. Run `pio run -e uno` and `pio run -e pro16MHzatmega328` and confirm both still
   build clean — the extraction must not change the board builds' behavior.
7. Run `pio check` and `clang-format` (per CLAUDE.md) over every touched/added
   file.

## Verification

- `pio test -e native` passes, covering all boundary cases listed above.
- `pio run -e uno` and `pio run -e pro16MHzatmega328` both build with no new
  warnings beyond whatever the codebase already emits.
- `grep -n "SWITCH_PRESS_" src/mode_switch2.cc` returns nothing (constants fully
  relocated, not duplicated).
- Manual read-through of `classify_press_duration()` against the original inline
  logic in both `read_button_1()` and `read_button_2()` confirms identical
  threshold values and boundary behavior (`>` vs `>=`) — a behavior change here
  would silently alter UC-001/UC-002 press-duration detection.
- `pio check` run clean (or any new finding justified inline per CLAUDE.md).

## Risks

- `env:native` accidentally inheriting `[env]`'s `lib_deps`/`build_flags` would
  try to fetch or compile Arduino-only libraries for the native platform and
  fail the build — mitigated by defining it standalone (see Scope).
- If PlatformIO's native test runner pulls in more of `src/` by default than
  intended (test builds can implicitly include library-resolved sources),
  `build_src_filter`/`test_filter` must be checked carefully, not assumed from
  the other `[env:...]` sections' filters.
- Low overall risk: the extracted function is small, pure, and has no behavior
  change intended — the main failure mode is a subtle `>` vs `>=` boundary
  mismatch between old and new code, which the Verification step's manual
  read-through and the explicit boundary test cases are meant to catch.

## Open questions

- None blocking. One implementation-time decision, not a blocker: whether
  `classify_press_duration()` treats a negative `elapsed_ms` as a defined input
  (e.g. always `quick`) or as a precondition the caller must never violate —
  pick whichever during implementation and note it in the function's one-line
  doc comment per CLAUDE.md's documentation convention.

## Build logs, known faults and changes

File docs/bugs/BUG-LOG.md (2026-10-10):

<!-- CONTRACT: deviations from intended behavior, tracked from report through root
     cause to fix. Not a duplicate of docs/requirements/ — a bug means something
     already documented (or implicitly assumed) isn't holding true in practice.
     Delete the BUG-EXAMPLE section once you've seen the shape. -->

# Bug Log

Convention: `BUG-###`, sequential, never renumbered. Status: `Open` → `Investigating`
→ `Fix Planned` → `Fixed` → (or `Won't Fix` / `Duplicate of BUG-0XX`). **Only the user
sets a bug to `Fixed`** — that's a claim about verified deployed behavior, not
something to self-report from having written a fix plan.

---

## BUG-EXAMPLE — Password reset link accepted after expiry

*(delete this section once you've seen the shape)*

**Severity:** High
**Status:** Fix Planned
**Reported:** YYYY-MM-DD
**Related requirements:** FR-EXAMPLE, UC-EXAMPLE (violates the "time-limited" part of both)
**Fix plan:** `plans/bugfix-reset-link-expiry-plan.md`

**Reproduction steps:**
1. Request a password reset
2. Wait past the stated expiry window (currently 1 hour)
3. Follow the link anyway

**Expected behavior:** Link is rejected with an "expired, request a new one" message
(per FR-EXAMPLE).

**Actual behavior:** Link still succeeds and resets the password.

**Root cause:** Expiry is checked against token creation time using the token's own
embedded claim, but that claim is client-suppliable and never verified against issue
time recorded server-side. *(Fill this in during investigation — leave `TBD` until
actually found in the code, not guessed from symptoms.)*

---

## BUG-001 — `pio check`/`pio run`/`pio test` warn about unknown `lib_deps_builtin`/`lib_deps_external` options

**Severity:** Low
**Status:** Fixed
**Reported:** 2026-10-09
**Related requirements:** None found. This is a build-tool configuration correctness
issue, not a user-facing functional behavior deviation — it violates the implicit
assumption that running the project's standard PlatformIO commands produces no
unexplained warnings, not any documented FR/NFR/UC.
**Fix plan:** `plans/bugfix-platformio-ini-unknown-options-plan.md`

**Reproduction steps:**
1. Run `pio check` (also reproducible with `pio run` and `pio test`) from the
   project root.
2. Observe the warnings printed before the rest of the command's output:
   ```
   Warning! Ignore unknown configuration option `lib_deps_builtin` in section [env]
   Warning! Ignore unknown configuration option `lib_deps_external` in section [env]
   ```

**Expected behavior:** These commands run without emitting warnings about
unrecognized configuration keys.

**Actual behavior:** Both warnings print on every invocation of `pio check`,
`pio run`, and `pio test`.

**Root cause:** `platformio.ini`'s `[env]` section (`platformio.ini:28-38`) defines
`lib_deps_builtin` and `lib_deps_external` as custom keys purely so `[env:uno]` and
`[env:pro16MHzatmega328]` can interpolate them into their own `lib_deps` via
`${env.lib_deps_builtin}` / `${env.lib_deps_external}` (`platformio.ini:48-50,
61-63`) — a DRY mechanism to share the library list across both board environments.
PlatformIO validates `[env]`/`[env:*]` sections against a known schema of option
names; `lib_deps_builtin` and `lib_deps_external` aren't recognized options for that
section type, so PlatformIO logs a warning and ignores them as configuration (while
still permitting `${env.*}` variable interpolation to read their literal text, which
is why the build itself isn't broken — only the warning is spurious).

---

<!-- Add new bugs via /fix-bug, or by hand — keep the section format: metadata lines,
     then Reproduction / Expected / Actual / Root Cause. A bug with no reproduction
     steps yet is a symptom report, not a bug entry — get concrete steps before
     assigning an ID if at all possible. -->

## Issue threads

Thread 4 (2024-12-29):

Change '595 names to match variables and/or so they match the PCB names

jhrg, 2024-12-29:
Fix this:
// Choose pins that cannot be used for hardware PWM
int serialDataPin = 8; // DS aka SER (serial data) input
int clockPin = 4;      // SHCP aka SRCLK (shift register clock) input
int latchPin = 7;      // STCP aka RCLK (register clock/latch) input

jhrg, 2024-12-31:
done

Closed 2024-12-31.

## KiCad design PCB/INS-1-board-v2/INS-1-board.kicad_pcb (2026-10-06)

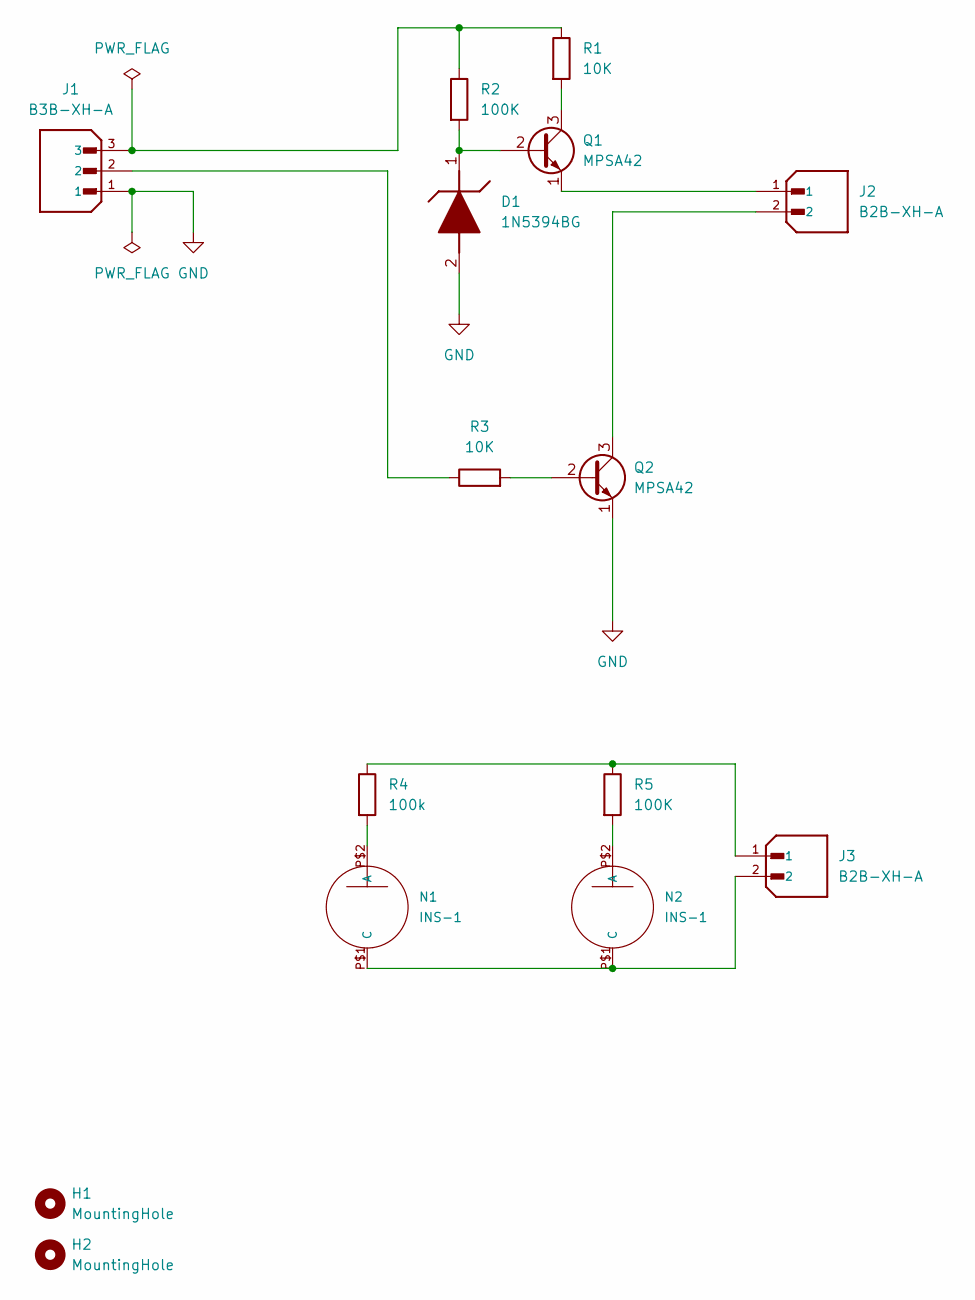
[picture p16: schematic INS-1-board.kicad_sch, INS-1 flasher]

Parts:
D1: 1N5394BG; DIOAD2260W109L864D349; Manufacturer_Part_Number 1N5374BG
H1, H2: MountingHole; MountingHole_2.7mm
J1: B3B-XH-A; JST_B3B-XH-A; PARTREV 7/4/21
J2, J3: B2B-XH-A; JST_B2B-XH-A; PARTREV N/A
N1, N2: INS-1; mynixies-INS-1
Q1, Q2: MPSA42; TO-92L_HandSolder
R1, R3: 10K; R_Axial_DIN0207_L6.3mm_D2.5mm_P7.62mm_Horizontal
R2, R5: 100K; R_Axial_DIN0207_L6.3mm_D2.5mm_P7.62mm_Horizontal
R4: 100k; R_Axial_DIN0207_L6.3mm_D2.5mm_P7.62mm_Horizontal

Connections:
GND: D1.2 (A), J1.1, Q2.1 (E)
unnamed: D1.1 (K), Q1.2 (B), R2.2
unnamed: J1.2, R3.1
unnamed: J1.3, R1.1, R2.1
unnamed: J3.1, R4.1, R5.1
unnamed: N1.P$2 (A), R4.2
unnamed: J3.2, N1.P$1 (C), N2.P$1 (C)
unnamed: N2.P$2 (A), R5.2
unnamed: Q1.3 (C), R1.2
unnamed: J2.1, Q1.1 (E)
unnamed: Q2.2 (B), R3.2
unnamed: J2.2, Q2.3 (C)

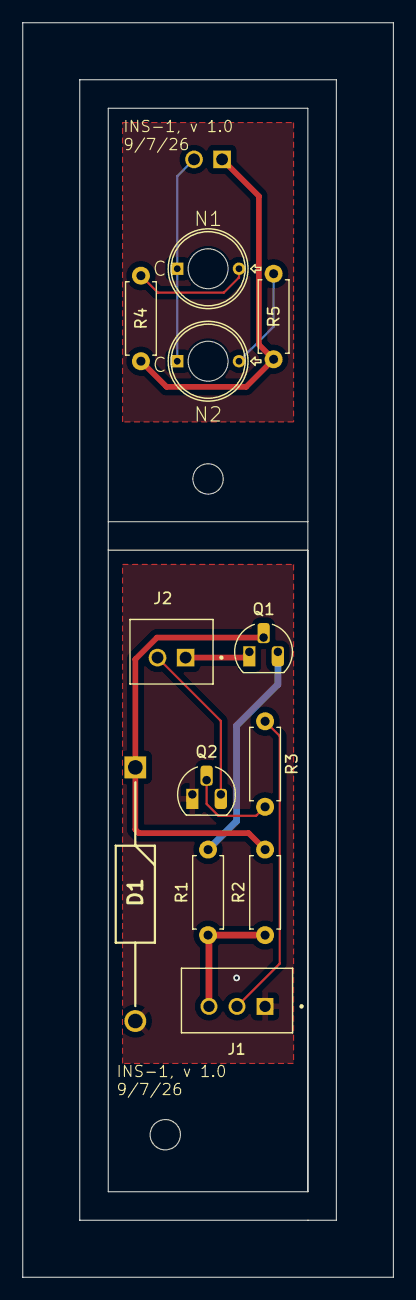
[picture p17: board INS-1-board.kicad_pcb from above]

Board: 2 copper layers, 33.0 x 111.8 mm, 15 parts (1 on the bottom side), 12 nets.

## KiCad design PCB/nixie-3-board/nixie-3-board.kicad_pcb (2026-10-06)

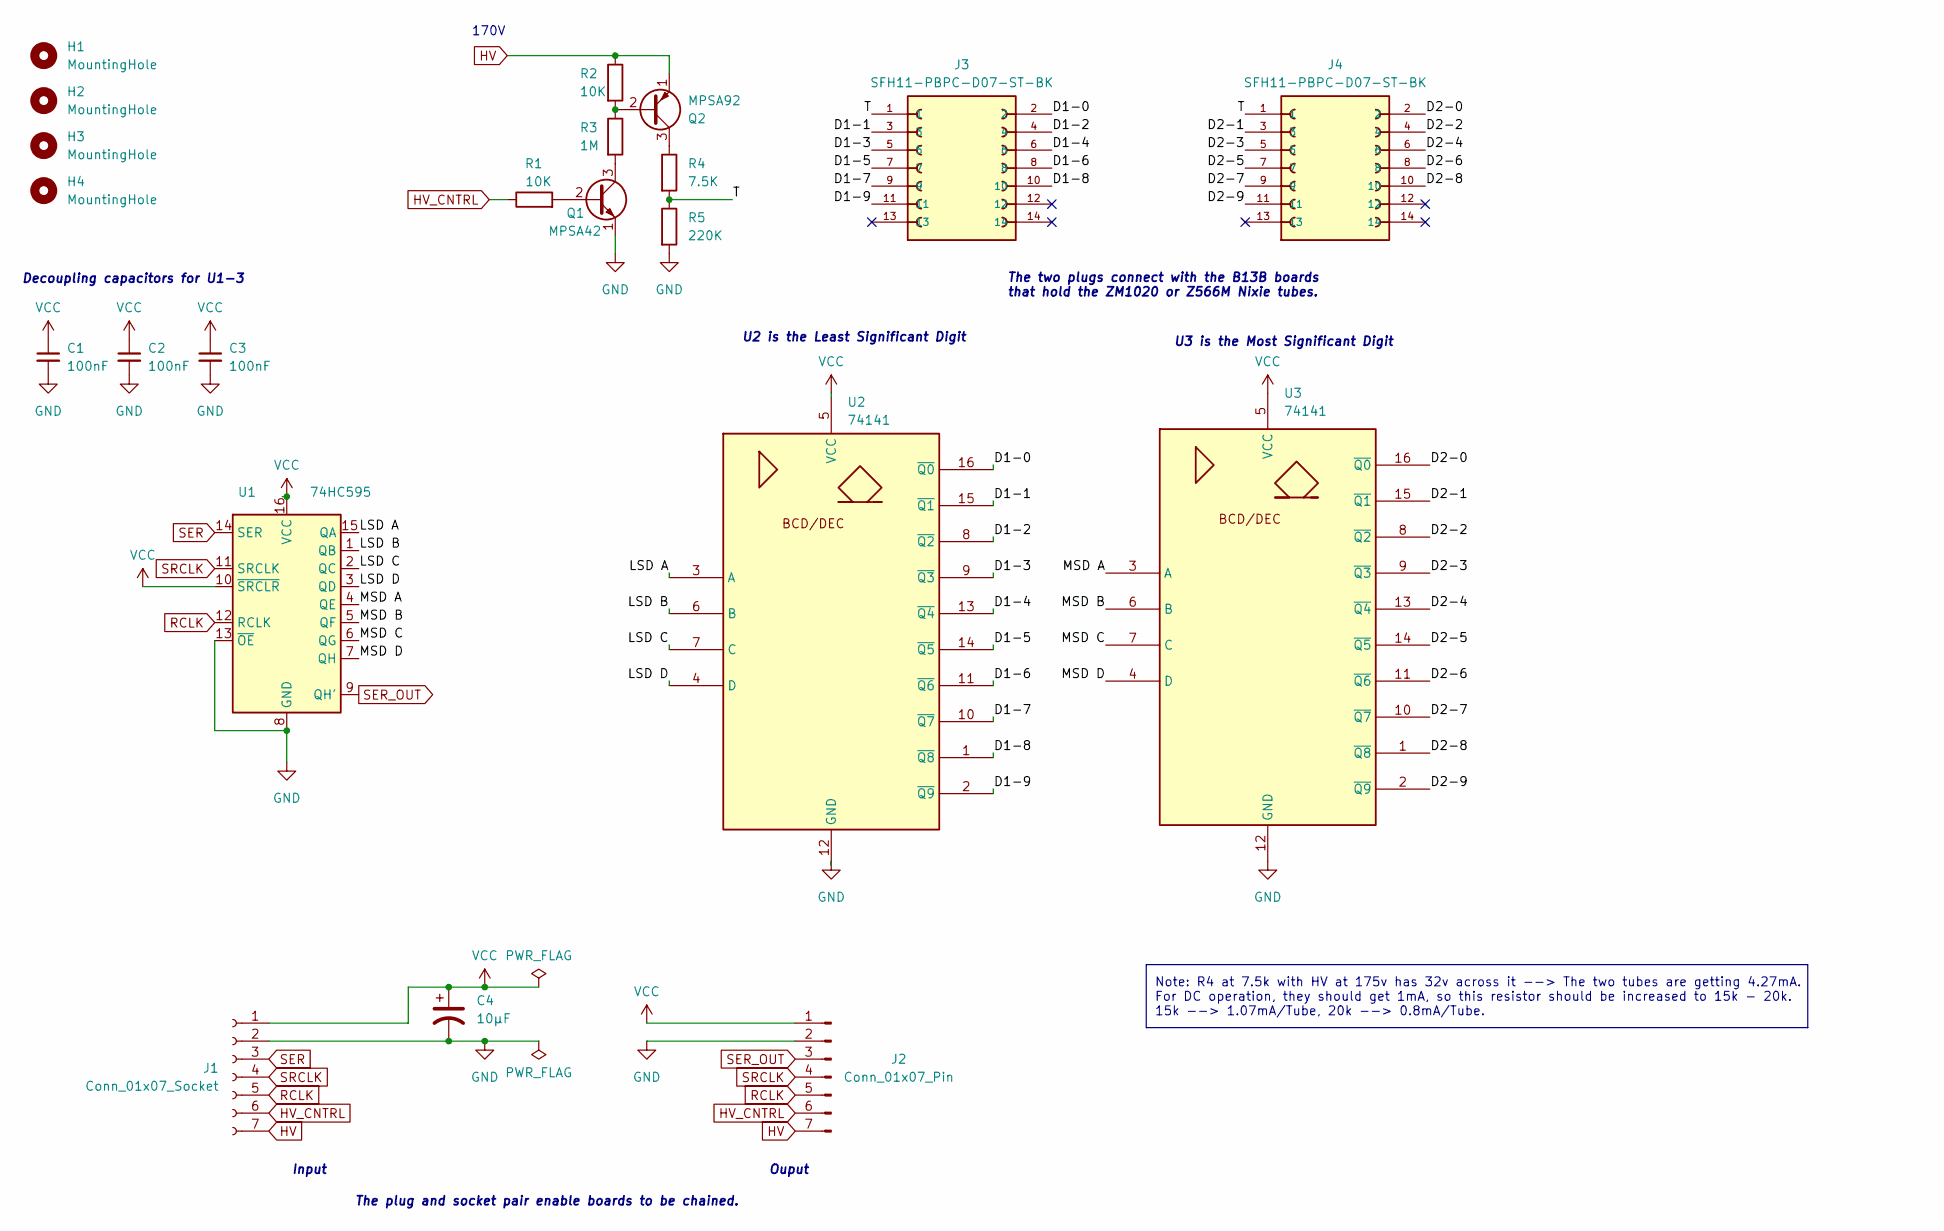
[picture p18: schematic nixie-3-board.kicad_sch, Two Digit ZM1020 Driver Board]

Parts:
C1, C2, C3: 100nF; K104Z15Y5VF5TL2_VIS
C4: 10µF; U1-E_NCH
H1, H2, H3, H4: MountingHole; MountingHole_2.7mm_M2.5_DIN965
J1: Conn_01x07_Socket; PinSocket_1x07_P2.54mm_Horizontal
J2: Conn_01x07_Pin; PinHeader_1x07_P2.54mm_Horizontal
J3, J4: SFH11-PBPC-D07-ST-BK; SULLINS_SFH11-PBPC-D07-ST-BK; PARTREV J
Q1: MPSA42; TO-92_HandSolder
Q2: MPSA92; TO-92_HandSolder
R1, R2: 10K; R_Axial_DIN0207_L6.3mm_D2.5mm_P7.62mm_Horizontal
R3: 1M; R_Axial_DIN0207_L6.3mm_D2.5mm_P7.62mm_Horizontal
R4: 7.5K; R_Axial_DIN0207_L6.3mm_D2.5mm_P7.62mm_Horizontal
R5: 220K; R_Axial_DIN0207_L6.3mm_D2.5mm_P7.62mm_Horizontal
U1: 74HC595; DIP-16_W7.62mm_Socket
U2, U3: 74141; DIP-16_W7.62mm_Socket

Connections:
/D1-0: J3.2, U2.16 (~Q0)
/D1-1: J3.3, U2.15 (~Q1)
/D1-2: J3.4, U2.8 (~Q2)
/D1-3: J3.5, U2.9 (~Q3)
/D1-4: J3.6, U2.13 (~Q4)
/D1-5: J3.7, U2.14 (~Q5)
/D1-6: J3.8, U2.11 (~Q6)
/D1-7: J3.9, U2.10 (~Q7)
/D1-8: J3.10, U2.1 (~Q8)
/D1-9: J3.11, U2.2 (~Q9)
/D2-0: J4.2, U3.16 (~Q0)
/D2-1: J4.3, U3.15 (~Q1)
/D2-2: J4.4, U3.8 (~Q2)
/D2-3: J4.5, U3.9 (~Q3)
/D2-4: J4.6, U3.13 (~Q4)
/D2-5: J4.7, U3.14 (~Q5)
/D2-6: J4.8, U3.11 (~Q6)
/D2-7: J4.9, U3.10 (~Q7)
/D2-8: J4.10, U3.1 (~Q8)
/D2-9: J4.11, U3.2 (~Q9)
/LSD A: U1.15 (QA), U2.3 (A)
/LSD B: U1.1 (QB), U2.6 (B)
/LSD C: U1.2 (QC), U2.7 (C)
/LSD D: U1.3 (QD), U2.4 (D)
/MSD A: U1.4 (QE), U3.3 (A)
/MSD B: U1.5 (QF), U3.6 (B)
/MSD C: U1.6 (QG), U3.7 (C)
/MSD D: U1.7 (QH), U3.4 (D)
/T: J3.1, J4.1, R4.2, R5.1
GND: C1.2, C2.2, C3.2, C4.2, J1.2, J2.2, Q1.1 (E), R5.2, U1.8 (GND), U1.13 (~OE), U2.12 (GND), U3.12 (GND)
HV: J1.7, J2.7, Q2.1 (E), R2.1
HV_CNTRL: J1.6, J2.6, R1.1
unnamed: Q1.2 (B), R1.2
unnamed: Q1.3 (C), R3.2
unnamed: Q2.2 (B), R2.2, R3.1
unnamed: Q2.3 (C), R4.1
RCLK: J1.5, J2.5, U1.12 (RCLK)
SER: J1.3, U1.14 (SER)
SER_OUT: J2.3, U1.9 (QH')
SRCLK: J1.4, J2.4, U1.11 (SRCLK)
VCC: C1.1, C2.1, C3.1, C4.1, J1.1, J2.1, U1.10 (~SRCLR), U1.16 (VCC), U2.5 (VCC), U3.5 (VCC)

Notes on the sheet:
U2 is the Least Significant Digit
Ouput
The plug and socket pair enable boards to be chained.
170V
Note: R4 at 7.5k with HV at 175v has 32v across it --> The two tubes are getting 4.27mA. For DC operation, they should get 1mA, so this resistor should be increased to 15k - 20k. 15k --> 1.07mA/Tube, 20k --> 0.8mA/Tube.
U3 is the Most Significant Digit
The two plugs connect with the B13B boards that hold the ZM1020 or Z566M Nixie tubes.
Input
Decoupling capacitors for U1-3

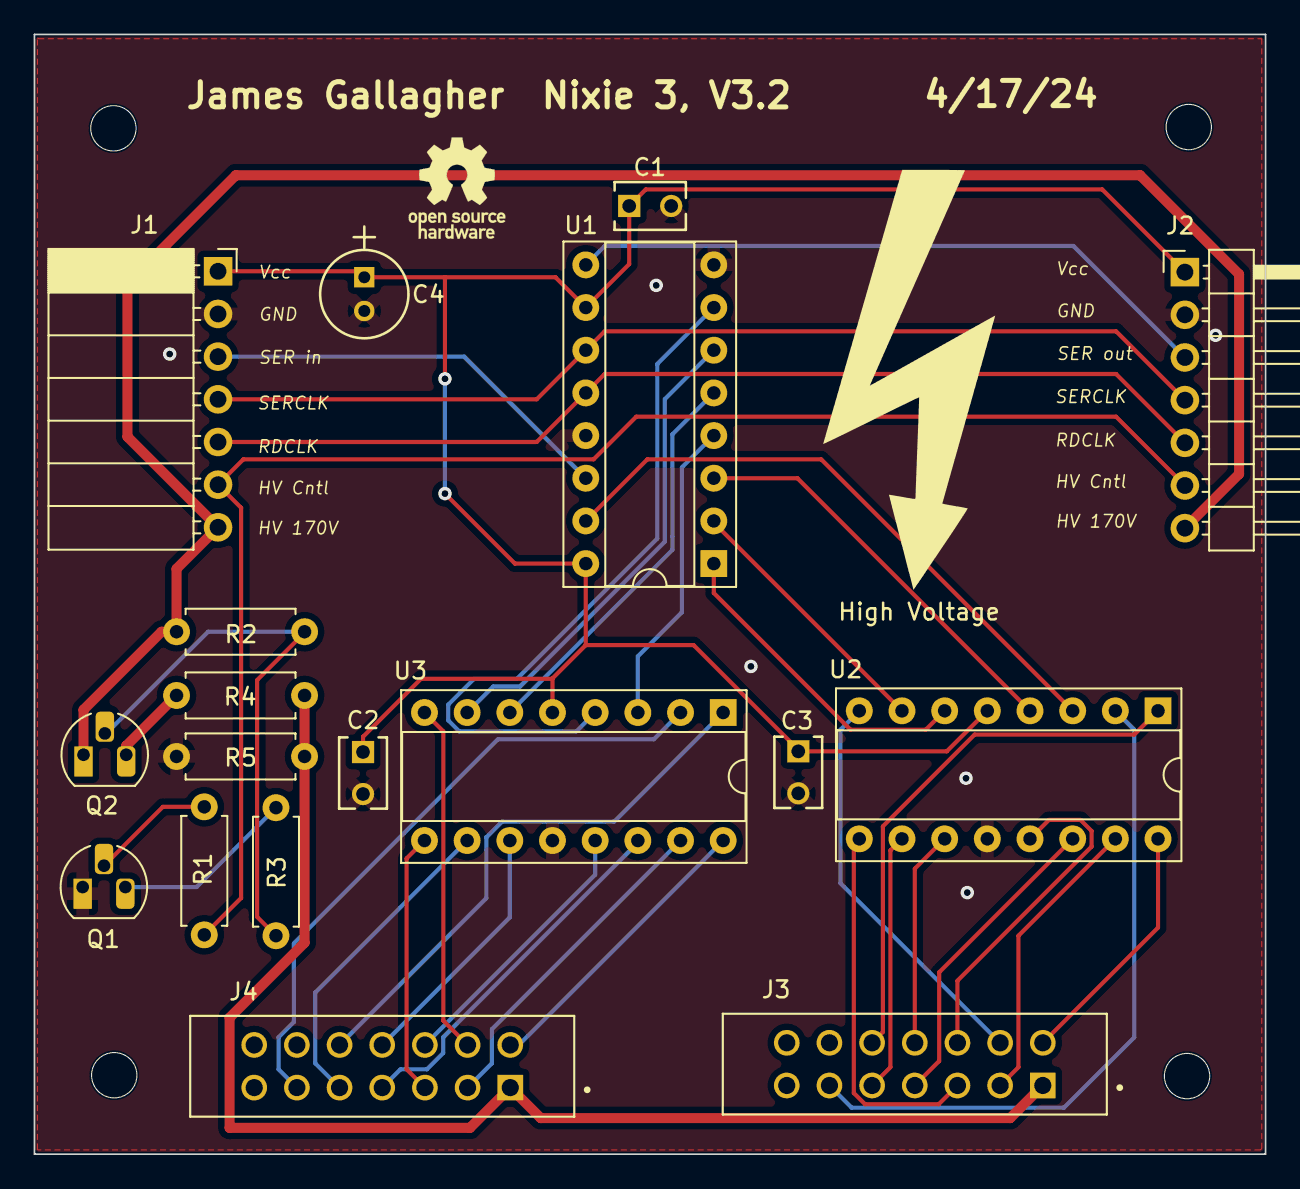
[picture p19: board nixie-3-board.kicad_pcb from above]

Board: 2 copper layers, 73.3 x 66.6 mm, 22 parts (0 on the bottom side), 41 nets.

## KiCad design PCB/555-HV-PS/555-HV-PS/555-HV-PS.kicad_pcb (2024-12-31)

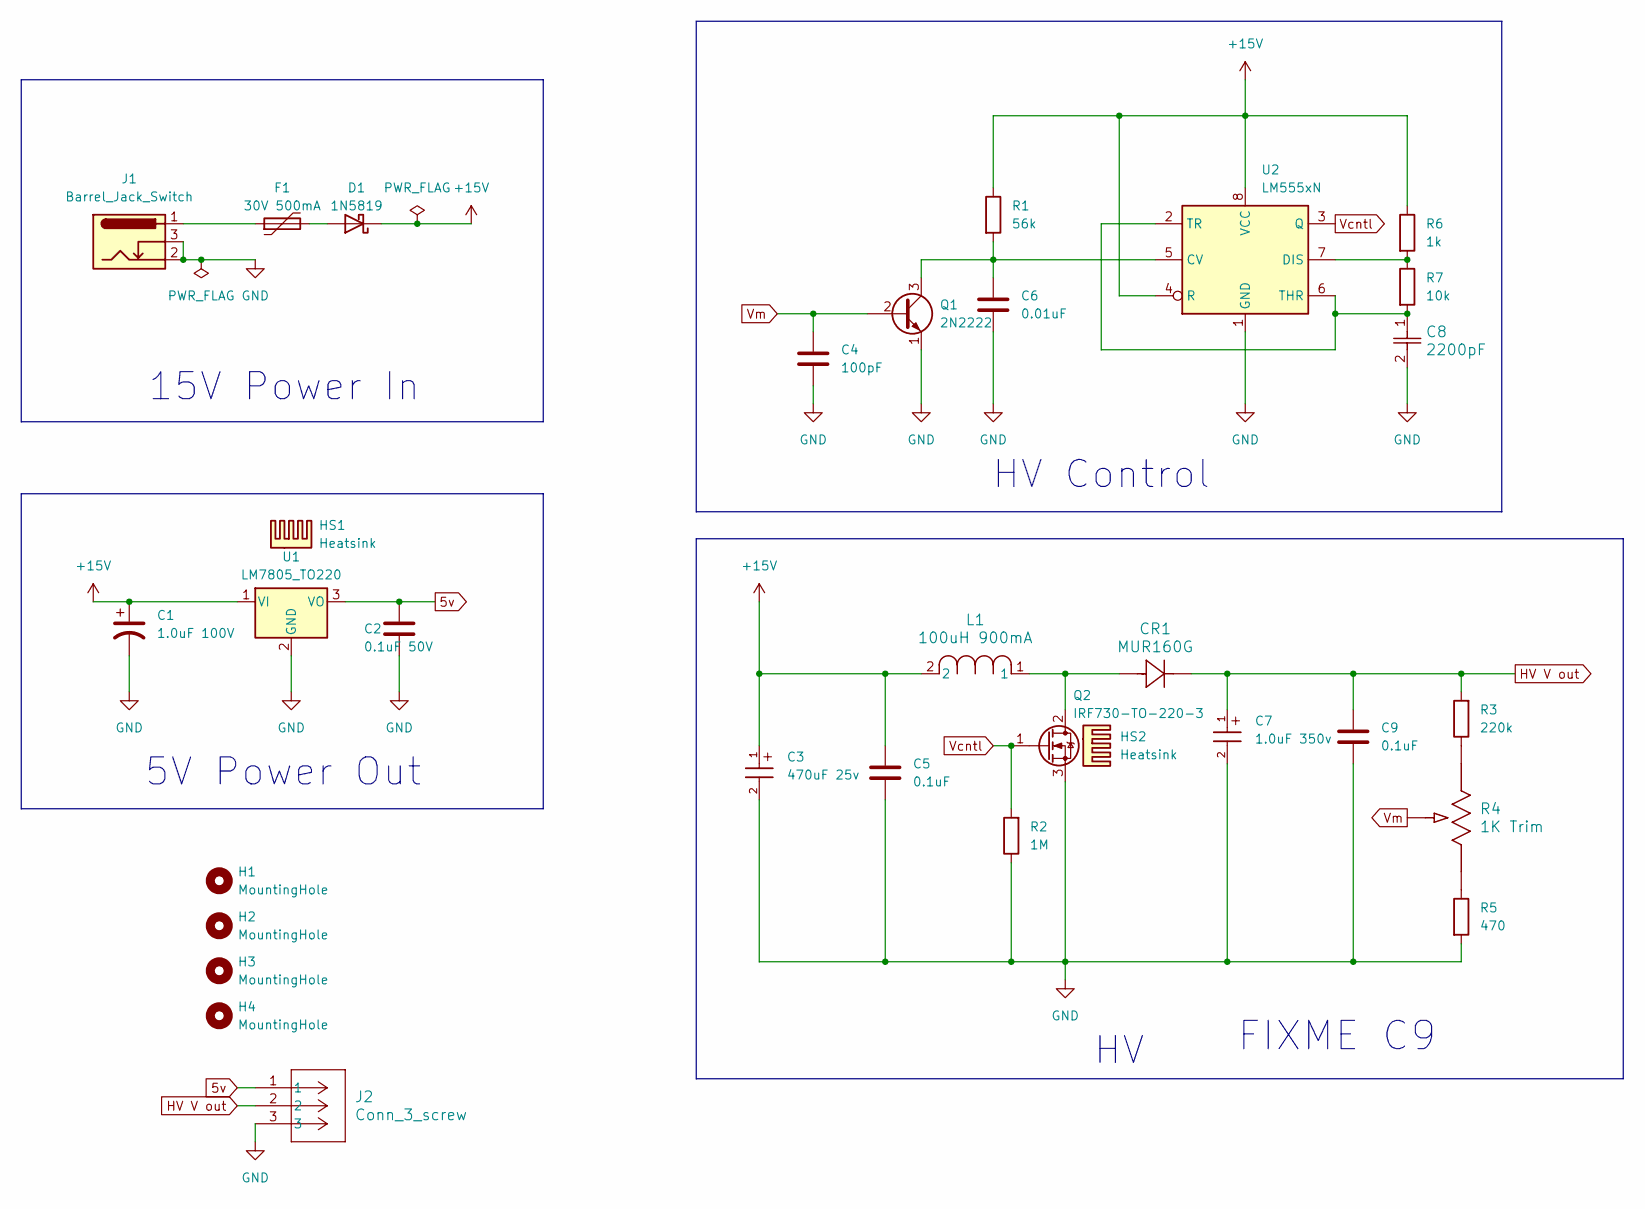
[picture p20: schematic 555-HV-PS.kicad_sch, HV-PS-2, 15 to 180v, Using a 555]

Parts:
C1: 1.0uF 100V; 1.0uF_160V_CAPPRD200W50D525H1250
C2: 0.1uF 50V; C_Disc_D5.0mm_W2.5mm_P5.00mm
C3: 470uF 25v; WCAP-ATUL_10X16_DXL_470uF-25v
C4: 100pF; C_Disc_D4.3mm_W1.9mm_P5.00mm
C5, C9: 0.1uF; C_Disc_D5.0mm_W2.5mm_P5.00mm
C6: 0.01uF; C_Disc_D4.3mm_W1.9mm_P5.00mm
C7: 1.0uF 350v; WCAP-ATET_8X11.5_DXL_
C8: 2200pF; CAP_S-SERIES_N-29-J_VIS
CR1: MUR160G
D1: 1N5819; D_DO-41_SOD81_P10.16mm_Horizontal
F1: 30V 500mA; AHRF050_30v_500mA_polyfuse
H1, H2, H3, H4: MountingHole; MountingHole_3mm
HS1, HS2: Heatsink; AVVID-577202B-00000G
J1: Barrel_Jack_Switch; BarrelJack_Horizontal
J2: Conn_3_screw; CONN3_OSTVN03A150_OST
L1: 100uH 900mA; IND_8095-WE-TI_8p3x10x5_WRE
Q1: 2N2222; TO-92_Inline
Q2: IRF730-TO-220-3; TO-220-3_Vertical
R1: 56k; R_Axial_DIN0207_L6.3mm_D2.5mm_P10.16mm_Horizontal
R2: 1M; R_Axial_DIN0207_L6.3mm_D2.5mm_P10.16mm_Horizontal
R3: 220k; R_Axial_DIN0207_L6.3mm_D2.5mm_P10.16mm_Horizontal
R4: 1K Trim; 10k_Trimmer_PV36W103C01B00
R5: 470; R_Axial_DIN0207_L6.3mm_D2.5mm_P10.16mm_Horizontal
R6: 1k; R_Axial_DIN0207_L6.3mm_D2.5mm_P10.16mm_Horizontal
R7: 10k; R_Axial_DIN0207_L6.3mm_D2.5mm_P10.16mm_Horizontal
U1: LM7805_TO220; TO-220-3_Vertical
U2: LM555xN; DIP-8_W7.62mm

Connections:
5v: C2.1, J2.1, U1.3 (VO)
+15V: C1.1, C3.1, C5.1, D1.1 (K), L1.2, R1.1, R6.1, U1.1 (VI), U2.4 (R), U2.8 (VCC)
GND: C1.2, C2.2, C3.2, C4.2, C5.2, C6.2, C7.2, C8.2, C9.2, J1.2, J1.3, J2.3, Q1.1 (E), Q2.3 (S), R2.1, R5.2, U1.2 (GND), U2.1 (GND)
HV V out: C7.1, C9.1, CR1.1, J2.2, R3.2
unnamed: D1.2 (A), F1.2
unnamed: F1.1, J1.1
unnamed: C6.1, Q1.3 (C), R1.2, U2.5 (CV)
unnamed: CR1.2, L1.1, Q2.2 (D)
unnamed: R3.1, R4.3
unnamed: R4.1, R5.1
unnamed: R6.2, R7.1, U2.7 (DIS)
unnamed: C8.1, R7.2, U2.2 (TR), U2.6 (THR)
Vcntl: Q2.1 (G), R2.2, U2.3 (Q)
Vm: C4.1, Q1.2 (B), R4.2

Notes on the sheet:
FIXME C9
15V Power In
HV Control
5V Power Out

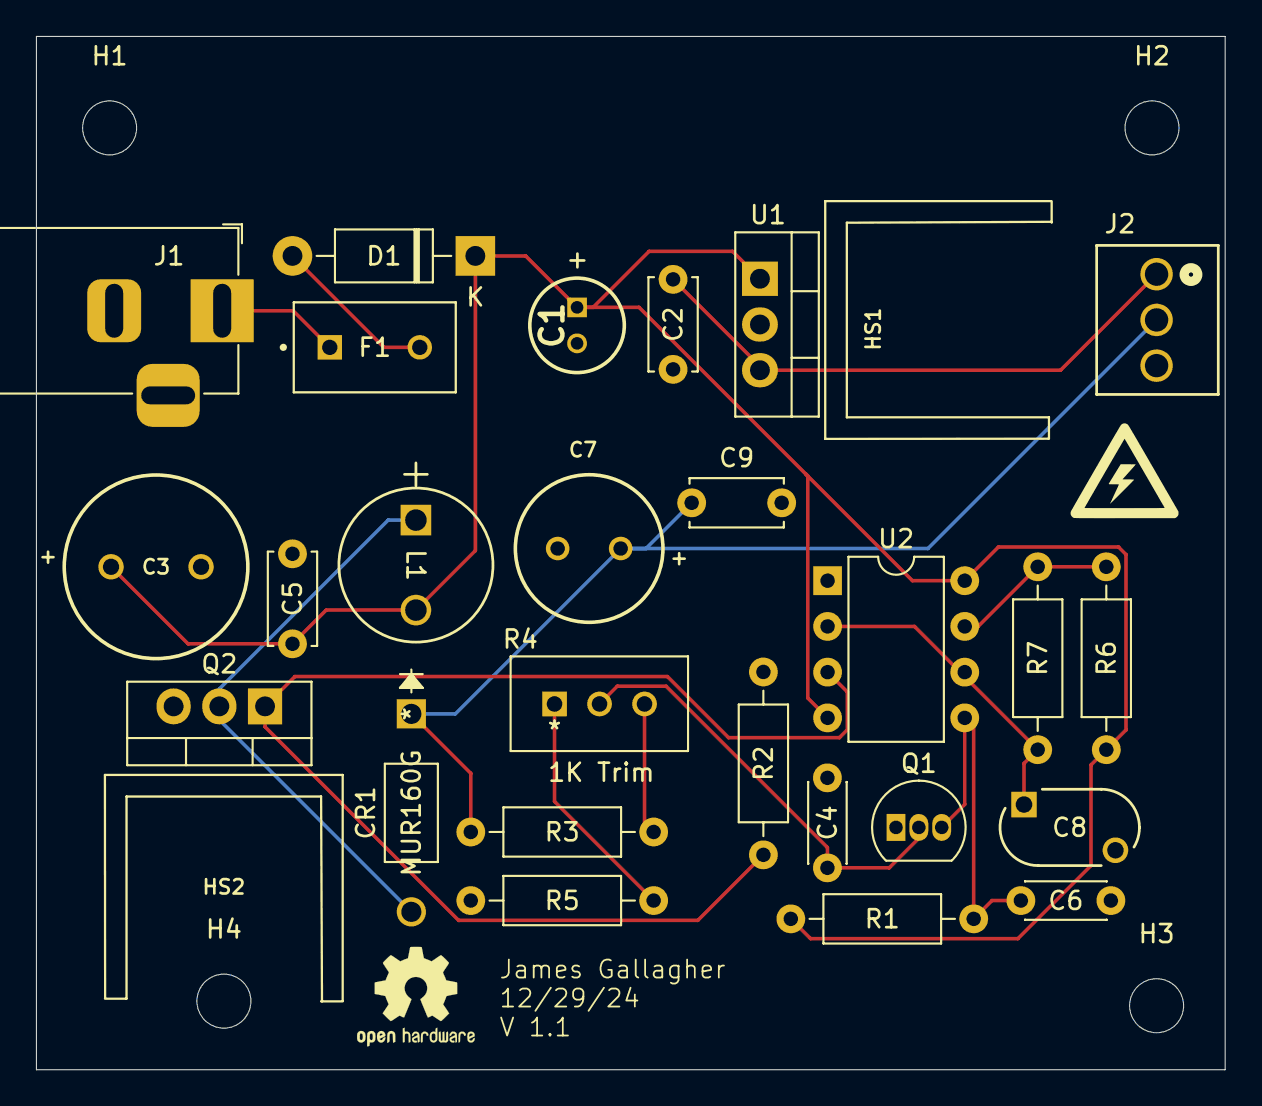
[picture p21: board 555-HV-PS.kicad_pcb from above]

Board: 2 copper layers, 66.0 x 57.4 mm, 32 parts (0 on the bottom side), 14 nets.

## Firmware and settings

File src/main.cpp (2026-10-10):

#include <Arduino.h>
#include <PinChangeInterrupt.h>

#include "RTC.h"
#include "brightness.h"
#include "mode_switch2.h"
#include "pins.h"
#include "print.h"

#define BAUD_RATE 115200

volatile int brightness = 0;
// Because this is C++, the definition must use 'extern' for this to be visible
// in another source file (i.e., translation unit). See RTC.cc. 7/15/25 jhrg
extern const int brightness_count[] = {255, 128, 76, 24, 0};

// BCD for 0, ..., 9 for the LSD, MSD.
uint8_t LSD[10] = {0x00, 0x01, 0x02, 0x03, 0x04, 0x05, 0x06, 0x07, 0x08, 0x09};
uint8_t MSD[10] = {0x00, 0x10, 0x20, 0x30, 0x40, 0x50, 0x60, 0x70, 0x80, 0x90};

/*
 * updateShiftRegister() - This function sets the REGISTER_CLK pin to low,
 * then calls the Arduino function 'shiftOut' to shift out contents
 * of variable 'data' in the shift register before putting 'REGISTER_CLK' high again.
 *
 * On a scope, it appears that the SERIAL_DATA pin is left high or low depending
 * on the last bit value written. I set it LOW so that every call has the
 * same initial condition, although I'm not sure that difference matters to
 * the 595 chips.
 *
 * I switched to this code over the ShiftRegister74HC595 library because I was
 * getting an odd error where sometimes the values ouput were corrupted. The
 * problem might have been noise on the breadboard or it might have been an
 * issue with interrupts. NB: It was noise; the HV PS that used the PID controller
 * was noisy and that was fixed by using a better HV PS. That also meant that
 * the PID controller could be dumped.
 */
void updateShiftRegister(uint8_t data) {
    digitalWrite(REGISTER_CLK, LOW);
    shiftOut(SERIAL_DATA, SERIAL_CLK, MSBFIRST, data);
    digitalWrite(REGISTER_CLK, HIGH);
    digitalWrite(SERIAL_DATA, LOW);
}

void setup() {
    Serial.begin(BAUD_RATE);
    DPRINT("boot\n");
    flush();

    RTC_setup();
    mode_switch_setup();

    cli();
    pinMode(REGISTER_CLK, OUTPUT);
    pinMode(SERIAL_CLK, OUTPUT);
    pinMode(SERIAL_DATA, OUTPUT);

    pinMode(LED_BUILTIN, OUTPUT);
    pinMode(HV_PWM_CONTROL, OUTPUT);
#if 0
    pinMode(INPUT_SWITCH, INPUT_PULLUP);

    attachInterrupt(digitalPinToInterrupt(INPUT_SWITCH), input_switch_push, RISING);
#endif
    digitalWrite(LED_BUILTIN, HIGH);
    digitalWrite(HV_PWM_CONTROL, HIGH);  // Start out bright
    sei();

    // Flash random digits at start up.
    int digit_time_ms = 50;
    int random_time_ms = 1000;
    do {
        uint8_t bits[2];
        bits[0] = MSD[random(10)] | LSD[random(10)];
        bits[1] = MSD[random(10)] | LSD[random(10)];

        cli();
        updateShiftRegister(bits[1]);
        updateShiftRegister(bits[0]);
        sei();
    
        delay(digit_time_ms);
        random_time_ms -= digit_time_ms;
    } while (random_time_ms > 0);

    digitalWrite(LED_BUILTIN, LOW);
}

void input_switch_quick_press() {
    brightness = next_brightness_index(brightness, sizeof(brightness_count) / sizeof(brightness_count[0]));
    DPRINTV("brightness: %d\n", brightness);
    analogWrite(HV_PWM_CONTROL, brightness_count[brightness]);
}

void loop() {
    uint8_t bits[2]; // 1 is the LSD pair, 0 the MSD pair
    static enum display_mode the_display_mode = mm_ss;  // initialized to mm_ss

    switch (read_button_1()) {
        case quick:
            input_switch_quick_press();
            break;
        case medium_2s:
            break;  // no-op; reserved for future task/feature
        case long_5s:
            break;  // no-op; reserved for future task/feature
        default:
            break;
    }

    switch (read_button_2()) {
        case quick:
            the_display_mode = toggle_display_mode(the_display_mode);
            DPRINTV("display mode: %s\n", the_display_mode == mm_ss ? "MM:SS" : "HH:MM");
            break;
        case medium_2s:
            break;  // no-op; reserved for future task/feature
        case long_5s:
            break;  // no-op; reserved for future task/feature
        default:
            break;
    }

    if (time_update_handler()) {
        switch (the_display_mode) {
            case mm_ss:
                bits[0] = MSD[digit_3] | LSD[digit_2];
                bits[1] = MSD[digit_1] | LSD[digit_0];
                break;

            case hh_mm:
                bits[0] = MSD[digit_5] | LSD[digit_4];
                bits[1] = MSD[digit_3] | LSD[digit_2];
                break;
        };

        // I don't know for sure that these cli/sei calls are needed. They seem to do no harm.
        cli();
        updateShiftRegister(bits[1]);
        updateShiftRegister(bits[0]);
        sei();
    }
}

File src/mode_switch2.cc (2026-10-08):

//  This example and code is in the public domain and may  be used without restriction and
//  without warranty.
//
// Example sketch  - Button Switch Using An External Interrupt
// '''''''''''''''''''''''''''''''''''''''''''''''''''''''''
//  This sketch demonstrates the use of a simple button switch which is processed by
//  an external interrupt process.  It presents a very different and alternative approach
//  for associating a button switch to an interrupt.
//
// The sketch is designed such that button status is only flagged as 'switched' AFTER
// 1. button is pressed AND then released, AND
// 2. elapse of the debounce period AFTER release
//
//  Note that the associated button interrupt handler function and the button_read()
//  function work together - the interrupt handler starts the on/off process and the
//  button_read() function completes/concludes it.  The interrupt handler can only restart AFTER
//  button reading and debounce is complete.  This ensures that only one interrupt trigger is
//  processed at a time.
//
// The button switch is wired in a standard configuration with a 10K ohm pull down resister which
// ensures the digital interrupt pin is kept LOW until the button switch is pressed  and
// raises it to HIGH (+5v).
//
// Operation of the button is demonstrated  by toggling the in built LED on and off.
//
// Based on a tutorial by ronbentley1 at
// From https://projecthub.arduino.cc/ronbentley1/button-switch-using-an-external-interrupt-16d57f

#include "mode_switch2.h"

#include <Arduino.h>

#include "PinChangeInterrupt.h"
#include "button_timing.h"
#include "pins.h"
#include "print.h"

#define LED LED_BUILTIN  // digital pin connected to LED, for testing of switch code only
bool led_status = LOW;   // start with LED off, for testing of switch code  only

// int button_switch = 2;  // external interrupt  pin

#define switched true                  // value if the button  switch has been pressed
#define triggered true                 // controls  interrupt handler
#define interrupt_trigger_type RISING  // interrupt  triggered on a RISING input
#define debounce 100                    // time to wait in milli secs

#if 0
volatile enum display_mode the_display_mode = mm_ss;
#endif

volatile bool interrupt_process_1_status = {
    !triggered  // start with no switch press pending,  i.e., false (!triggered)
};

volatile bool interrupt_process_2_status = {
    !triggered  // start with no switch press pending,  i.e., false (!triggered)
};

bool initialization_complete = false;  // inhibit any interrupts until initialisation is complete

//
// ISR for  handling interrupt triggers arising from associated button switch
//
void button_1_interrupt_handler() {
    if (initialization_complete == true) {  //  all variables are initialised so we are okay to continue to process this interrupt
        if (interrupt_process_1_status == !triggered) {
            // new interrupt so okay  start a new button read process -
            // now need to wait for button release  plus debounce period to elapse
            // this will be done in the button_read  function
            if (digitalRead(INPUT_SWITCH) == HIGH) {
                // button  pressed, so we can start the read on/off + debounce cycle which will
                //  be completed by the button_read() function.
                digitalWrite(LED, HIGH);
                interrupt_process_1_status = triggered;  // keep this ISR 'quiet' until button read fully completed
            }
        }
    }
}  // end of button_1_interrupt_handler

void button_2_interrupt_handler() {
    if (initialization_complete == true) {  //  all variables are initialised so we are okay to continue to process this interrupt
        if (interrupt_process_2_status == !triggered) {
            // new interrupt so okay  start a new button read process -
            // now need to wait for button release  plus debounce period to elapse
            // this will be done in the button_read  function
            if (digitalRead(MODE_SWITCH) == HIGH) {
                // button  pressed, so we can start the read on/off + debounce cycle which will
                //  be completed by the button_read() function.
                digitalWrite(LED, HIGH);
                interrupt_process_2_status = triggered;  // keep this ISR 'quiet' until button read fully completed
            }
        }
    }
}  // end of button_2_interrupt_handler

enum switch_press_duration read_button_1() {
    int button_reading;
    // static variables because we need to retain old values  between function calls
    static bool switching_pending = false;
    static long elapse_timer;
    static long initial_time = 0;
    if (interrupt_process_1_status == triggered) {
        //  interrupt has been raised on this button so now need to complete
        // the button  read process, ie wait until it has been released
        // and debounce time elapsed
        button_reading = digitalRead(INPUT_SWITCH);
        if (button_reading == HIGH) {
            // switch is pressed, so start/restart wait for button release, plus end of debounce process
            switching_pending = true;
            elapse_timer = millis();  // start elapse timing for debounce checking
            if (initial_time == 0)
                initial_time = elapse_timer;
        }
        if (switching_pending && button_reading == LOW) {
            // switch was pressed, now released, so check  if debounce time elapsed
            if (millis() - elapse_timer > debounce) {
                // debounce time elapsed, so switch press cycle complete
                digitalWrite(LED, LOW);
                switching_pending = false;                // reset for next button press interrupt cycle
                interrupt_process_1_status = !triggered;  // reopen ISR for business now button on/off/debounce cycle complete
                long elapsed = millis() - initial_time;   // measure time from the initial button press
                initial_time = 0;
                DPRINTV("button 1 elapsed: %ld\n", elapsed);
                return classify_press_duration(elapsed);
            }
        }
    }
    return none;  // either no press request or debounce period not elapsed
}  // end of read_button_1 function
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

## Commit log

2023-10-23 Updates: Added ShiftRegister74HC595, print.cc and modde_switch.cc
    [nixie-3-board.kicad_pcb, nixie-3-board.kicad_sch]
2023-10-23 Fixed the dimming feature
    The mode switch code and brightness control are now
    held in mode_switch.cc There is no need to poll the
    input switch. Instead the callback updates the brightness.
    [main.cpp]
2024-01-03 Added more stuff for PCB abd added docs
    [nixie-3-board.kicad_pcb, nixie-3-board.kicad_sch]
2024-01-04 new layout - might work. Needs holes, markings, screw terminals
    [nixie-3-board.kicad_pcb, nixie-3-board.kicad_sch]
2024-02-11 Version 3 of the driver PCB
    Adds decouping caps and re-orders digits so LSD is on the right.
    [nixie-3-board.kicad_pcb, nixie-3-board.kicad_sch]
2024-02-11 Added capacitor footprints
2024-02-11 Fixed mistakes, v3.1
    [nixie-3-board.kicad_pcb, nixie-3-board.kicad_sch]
2024-02-12 Better names for the decoupling cap footprint files
    Also corrected the value for the PS decoupling cap from 100uF to 10uF
    [nixie-3-board.kicad_pcb, nixie-3-board.kicad_sch]
2024-04-10 Use new board version
2024-04-18 Added high voltage symbol to display PCB
    [nixie-3-board.kicad_pcb]
2024-08-10 Fixed the 1Hz ISR so that only one of update_time or get_time is true.
    The ISR was written so that when get_time was true, update_time
    was also true. That caused the time to be updated twice and which
    made for a glitch once every few minutes where the time would advance
    only to be reset a moment later (because code that polls the flags
    set by the ISR runs very often).
    [RTC.cc]
2024-08-31 Removed an object copy from print_time() debug function
2024-09-01 Needed to set pin 10 as output - fixed using hv_ps_test.cc
    [hv_ps.cc, hv_ps_test.cc]
2024-09-01 How often hv_ps_adjust() affects output stability. Why?
    [hv_ps.cc, hv_ps_test.cc]
2024-09-04 Use the HV PS driven by the arduino PWM signal.
2024-09-05 Change the main loop and DEBUG switch
2024-09-15 Removed HV PS PID controller and added a flashing colon.
    Should have been two branches. Anyway, the PID controller is gone.
    Use a dedicated HV PS that does not need the MCU.
    Added a flashing colon and simplified the use of the clock. There
    seems to be no need to limit the use of the I2C bus to read from the
    DS3231 to once every 10s; it seems to be fine to read every second.
2024-09-15 Retired the HV PS code, removed unused libs, added KiCAD files
    [logic.kicad_sch, nixie-3-logic-board.kicad_sch]
2024-12-30 Removed unused INPUT_SWITCH, dropped PORTB use by the RTC
    [nixie-3-board.kicad_sch]
2024-12-31 Added PCB files for the HV PS and INS tube circuits
    [555-HV-PS.kicad_pcb, 555-HV-PS.kicad_sch, INS-1-board.kicad_pcb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]
2024-12-31 More 55 HV PS files
    [555-HV-PS.csv]
2024-12-31 Most of the switch #define for pins and a single pin def header is complete
2025-01-04 The HH:MM and MM:SS modes work - 2s+ mode switch (but < 5s)
2025-01-20 New mode switching code.
2025-03-15 Fixed some include issues.
    [mode_switch2.cc]
2025-07-02 KiCAD updates for version 8
    [INS-1-board.kicad_sch, nixie-3-board.kicad_pcb]
2025-07-02 Added INS-1-board-v2.zip
2025-07-06 Edits to the 555 HV PS circuit and added some info
    I added a README to the PCB/555-HV-PS directory with some
    images from the ocilloscope.
    [555-HV-PS.kicad_sch]
2025-07-06 Moved old INS-1 board to retired and updated INS-1 v2 board.
    [INS-1-board.kicad_pcb, INS-1-board.kicad_sch]
2025-07-06 Board update
2025-07-16 Add PWM dimming for the INS-1 colon.
2025-07-16 Added INS-1-v2 schematic and board
    [1N5948BRLG.step, INS-1-board.kicad_pcb, INS-1-board.kicad_sch]
2025-07-29 Initial version of mode switch on pin 6
2025-07-30 Added a second button switch.
2026-02-28 Comment fix to main.cpp
    [main.cpp]
2026-10-06 Moved docs to hv-ps-docs for the claude swe framework
    [555-HV-PS.kicad_sch, INS-1-board.kicad_pcb, INS-1-board.kicad_sch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]
2026-10-08 New swe framework
2026-10-09 Task-001 (mode switch tests) done
2026-10-09 Task-002: Display functions to short press of button 1 and 2
    [main.cpp]
2026-10-11 Phase 1 (set-time-set-date-mode-plan): add clock_mode state machine
    Add include/clock_mode.h and src/clock_mode.cc: operating-mode/field
    enums, next_operating_mode/next_time_field/next_date_field cycling,
    direction-aware adjust_*_value() wraparound for hour/minute/month/day/
    year (supporting both button 1's increment and button 2's decrement),
    and blank_if_selected() for the ~1 Hz field-selection blink. Pure C++,
    no Arduino.h, unit-tested under env:native (test_clock_mode).
    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
2026-10-11 Phase 2 (set-time-set-date-mode-plan): RTC field commit + date render + blink phase
    Add commit_hour_or_minute()/commit_month_day_or_year() to RTC.cc: apply one
    adjust_*_value() step to the current RTC time/date and write it back
    immediately via rtc.adjust(), resetting seconds to :00 for the time case.
    Wire time_update_handler() to take an operating_mode parameter and render
    the date (update_display_with_date()) instead of the time when the mode is
    set_date. Promote the 2Hz ISR's local tick-tok to a file-scope blink_phase
    and expose it via blink_off_phase(), giving main.cpp's rendering code (Phase
    3) the ~1 Hz signal NFR-001 needs to blink the field selected for editing.
    main.cpp's one time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
    [RTC.cc, main.cpp]
2026-10-11 Phase 3 (set-time-set-date-mode-plan): wire button dispatch + rendering
    Add the_operating_mode/the_time_field/the_date_field statics to loop() and
    make both buttons' quick-press and button 1's 2-second-press context-aware:
    - Button 1 quick press: brightness cycling in Running mode (unchanged);
    increments the selected field in Set Time/Set Date mode.
    - Button 2 quick press: display-mode toggle in Running mode (unchanged);
    decrements the selected field in Set Time/Set Date mode.
    - Button 1 2-second press: no-op in Running mode (unchanged); advances field
    selection in Set Time/Set Date mode.
    - Button 2 2-second press: cycles Running -> Set Time -> Set Date -> Running,
    resetting field s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
    [main.cpp]

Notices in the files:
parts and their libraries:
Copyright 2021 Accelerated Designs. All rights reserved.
